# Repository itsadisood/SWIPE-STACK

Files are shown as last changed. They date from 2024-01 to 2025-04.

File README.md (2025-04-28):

# SWIPE-STACK

**SWIPE-STACK** is a modern re-implementation of the classic puzzle game *Tetris*, featuring a wireless glove controller and a dynamic LED-matrix-based main hub.

This project combines embedded systems design, wireless communication, real-time graphics processing, and custom hardware to create an innovative and portable gaming experience.

---

## Project Overview

The system consists of two main components:

### Glove Module
- **Input Device**: A wearable glove capturing hand movements and gestures.
- **Key Components**:
  - **IMU Sensor**: Collects motion and orientation data.
  - **STM32 Microcontroller**: Processes IMU data and converts it into game control inputs.
  - **HM19 Bluetooth Module**: Communicates inputs wirelessly to the hub via UART.
  - **LiPo Battery**: Powers the glove, with battery management provided by an off-the-shelf controller.

### Main Hub
- **Game Console**: Executes game logic, receives user input, and manages displays.
- **Key Components**:
  - **STM32 Microcontroller**: Runs the game engine and display drivers.
  - **HM19 Bluetooth Module**: Receives input data from the glove.
  - **64x32 LED Matrix Display**: Displays the active game screen, driven by a custom parallel interface using DMA and timers.
  - **OLED 16x2 Text Display**: Shows the current score and level via SPI.
  - **TI Buck Converter**: Provides regulated power for the system.

Each STM32 project (`Hub/` and `Glove/`) follows the typical CubeIDE structure, including source files (`Core/`), drivers (`Drivers/`), project configuration (`.ioc`), and build settings.

---

## Repository Structure

- **Hub/** – Firmware for the main hub (STM32 project using STM32Workbench)
- **Glove/** – Firmware for the glove controller (STM32 project using STM32Workbench)
- **Electrical/** – Hardware design files (schematics, PCB layouts)
- **Mechanical/** – Mechanical design files (CAD models for glove and hub enclosures)
- **README.md** – Project overview and documentation (this file)

---
## Features

- **Wireless Glove Controller**: Real-time gesture input using an IMU and STM32 MCU.
- **Bluetooth Communication**: Low-latency UART-based HM19 Bluetooth link.
- **Custom LED Matrix Driver**: High-speed, multiplexed driving of a 64x32 RGB LED matrix using DMA and timers.
- **Embedded Game Engine**: Fully on-board Tetris-like game running on STM32 microcontroller.
- **Text-Based Display**: OLED screen displaying real-time score and level information.
- **Portable and Modular Design**: Custom PCBs, enclosures, and battery-powered operation.

---

## Demo

Check out a live demo of SWIPE-STACK here:  
SWIPE-STACK Demo Video (https://www.youtube.com/watch?v=645_PaOeo9Y&t=164s)

👉 [Watch the demo on YouTube](https://www.youtube.com/watch?v=645_PaOeo9Y&t=164s)

---

## Contributors

- Aditya Sood
- Alex Chitsazzadeh
- Vishnu Lagudu
- Justin Cambridge

---

## Notes

- This project is not intended for direct plug-and-play usage.
- Hardware assembly, flashing, and Bluetooth setup are required to build a fully functioning system.
- Schematics and mechanical models are provided for reference and reproduction.
- All firmware was developed using [STM32SystemWorkbench](https://www.st.com/en/development-tools/stm32cubeide.html).

---

## Acknowledgments

- STM32Cube HAL Drivers
- Public domain versions of the classic Tetris game logic
- Open-source hardware design inspirations for LED matrix driving techniques

---

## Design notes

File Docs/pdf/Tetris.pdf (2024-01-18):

## TETRIS GAME LOGIC

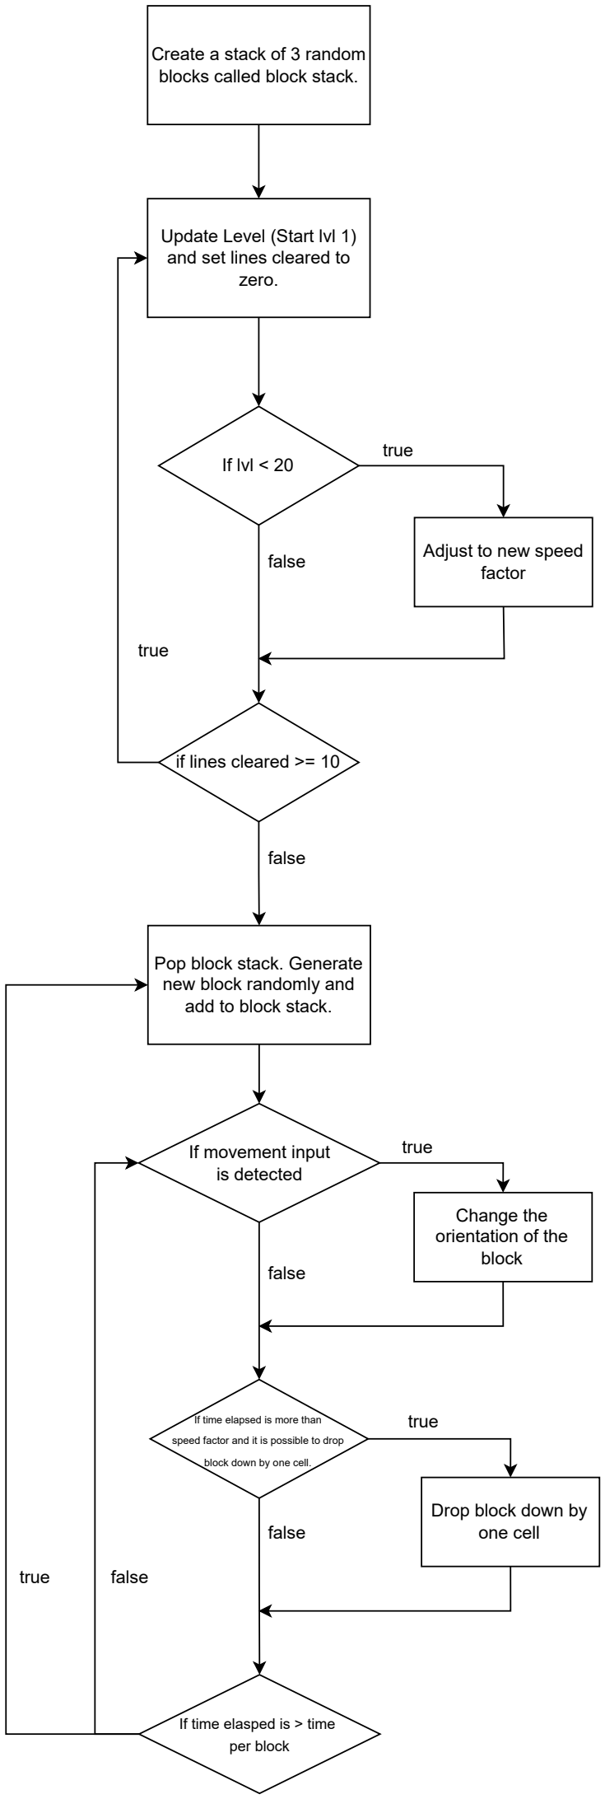
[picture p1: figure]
Update Level (Start lvl 1) and set lines cleared to zero.; Create a stack of 3 random blocks called block stack.; If lvl < 20; Adjust to new speed factor; true; false; if lines cleared >= 10; If movement input is detected; Change the orientation of the block; If time elapsed is more than; speed factor and it is possible to drop; block down by one cell.; Pop block stack. Generate new block randomly and add to block stack.; If time elasped is > time per block; Drop block down by one cell

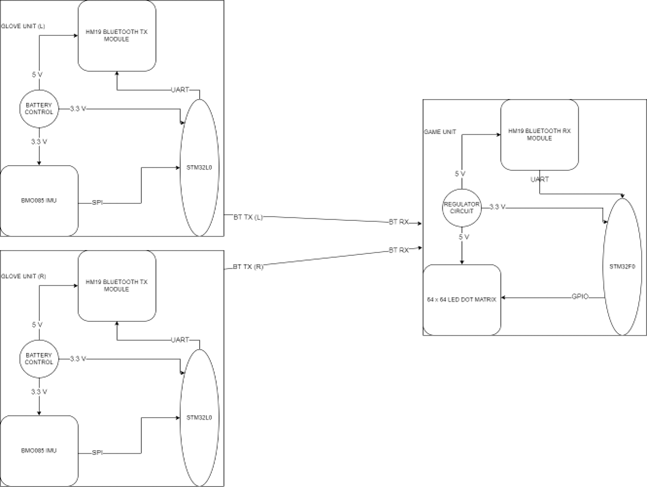
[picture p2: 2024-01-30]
Docs/pdf/Overall_System_Diagram.png

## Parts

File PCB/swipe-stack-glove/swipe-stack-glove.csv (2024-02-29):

# | Reference | Qty | Both Gloves | Value | Footprint | DNP
1 | C1, C2, C3, C6, C8, C9, C10, C11, C12, C13, C14 | 11 | 22 | 0.1uF | Capacitor_SMD:C_0805_2012Metric_Pad1.18x1.45mm_HandSolder
2 | C4, C5 | 2 | 4 | 22pF | Capacitor_SMD:C_0805_2012Metric_Pad1.18x1.45mm_HandSolder
3 | C7 | 1 | 2 | 10uF | Capacitor_SMD:C_0805_2012Metric_Pad1.18x1.45mm_HandSolder
4 | D1, D2 | 2 | 4 | green | LED_SMD:LED_0805_2012Metric_Pad1.15x1.40mm_HandSolder
5 | D3 | 1 | 2 | red | LED_SMD:LED_0805_2012Metric_Pad1.15x1.40mm_HandSolder
6 | D4 | 1 | 2 | blue | LED_SMD:LED_0805_2012Metric_Pad1.15x1.40mm_HandSolder
7 | H1 | 1 | 2 | B_TopLeft | MountingHole:MountingHole_2.5mm
8 | H2 | 1 | 2 | B_TopRight | MountingHole:MountingHole_2.5mm
9 | H3 | 1 | 2 | B_BottomLeft | MountingHole:MountingHole_2.5mm
10 | H4 | 1 | 2 | B_BottomRight | MountingHole:MountingHole_2.5mm
11 | J2 | 1 | 2 | Polulu Regulator | Connector_PinHeader_2.54mm:PinHeader_1x05_P2.54mm_Vertical
12 | J3, J4, J5 | 3 | 6 | Conn_01x01_Pin | Connector_PinHeader_2.54mm:PinHeader_1x01_P2.54mm_Vertical
13 | J6 | 1 | 2 | Conn_01x04 | Connector_PinHeader_2.54mm:PinHeader_1x04_P2.54mm_Vertical
14 | R1, R6 | 2 | 4 | 100k | Resistor_SMD:R_0805_2012Metric_Pad1.20x1.40mm_HandSolder
15 | R2, R3, R7 | 3 | 6 | 1k | Resistor_SMD:R_0805_2012Metric_Pad1.20x1.40mm_HandSolder
16 | R4 | 1 | 2 | 470 | Resistor_SMD:R_0805_2012Metric_Pad1.20x1.40mm_HandSolder
17 | R9, R11, R12 | 3 | 6 | 1k | LED_SMD:LED_0805_2012Metric_Pad1.15x1.40mm_HandSolder
18 | R10 | 1 | 2 | 510 | LED_SMD:LED_0805_2012Metric_Pad1.15x1.40mm_HandSolder
19 | SW1, SW2, SW3, SW4 | 4 | 8 | SW_Push | Button_Switch_SMD:SW_SPST_Omron_B3FS-100xP | digikey
20 | U1 | 1 | 2 | STM32F091RCTx | Package_QFP:LQFP-64_10x10mm_P0.5mm | digikey
21 | U2 | 1 | 2 | BNO085 | Package_LGA:LGA-28_5.2x3.8mm_P0.5mm
22 | U3 | 1 | 2 | MAX7375AXR805 | Package_TO_SOT_SMD:SOT-323_SC-70_Handsoldering
23 | U4 | 1 | 2 | HM-19 | GlovePCB:HM-11-MODULE
24 | U5 | 1 | 2 | Adafruit Charger | GlovePCB:AdaFruit Charger | ada
25 | U6 | 1 | 2 | BatteryCell | GlovePCB:battery_cell | ada
26 | XTAL1 | 1 | 2 | ECX-.327-CDX-1293 | GlovePCB:XTAL_ECS-.327-12.5-34RR-TR

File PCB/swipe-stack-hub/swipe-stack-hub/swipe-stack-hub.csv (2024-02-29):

Source: | C:\Users\justi\Documents\SWIPE-STACK\PCB\swipe-stack-hub\swipe-stack-hub.kicad_sch
Date: | 2/21/2024 10:18:29 AM
Tool: | Eeschema 7.0.10
Generator: | C:\Users\justi\AppData\Local\Programs\KiCad\7.0\bin\scripting\plugins/bom_csv_grouped_by_value.py
Component Count: | 60
Collated Components:
Item | Qty | Reference(s) | Value | LibPart | Footprint | Datasheet | DNP | Description
1 | 2 | C1, C3 | 10uF | Device:C_Small | Capacitor_SMD:C_0805_2012Metric_Pad1.18x1.45mm_HandSolder | ~
2 | 4 | C2, C4, C6, Cboot1 | 0.1uF | Device:C_Small | Capacitor_SMD:C_0805_2012Metric_Pad1.18x1.45mm_HandSolder | ~
3 | 5 | C5, C7, C8, C9, C10 | .1uF | Device:C | Capacitor_SMD:C_0805_2012Metric_Pad1.18x1.45mm_HandSolder | ~
4 | 1 | C11 | 250uF | Device:C_Polarized_Small | Capacitor_SMD:C_0805_2012Metric_Pad1.18x1.45mm_HandSolder | ~
5 | 1 | C12 | .05uF | Device:C | Capacitor_SMD:C_0805_2012Metric_Pad1.18x1.45mm_HandSolder | ~
6 | 2 | Cin1, Cin2 | 2.2uF | Device:C_Small | Capacitor_SMD:C_0805_2012Metric_Pad1.18x1.45mm_HandSolder | ~
7 | 1 | Cout1 | 22uF | Device:C_Small | Capacitor_SMD:C_0805_2012Metric_Pad1.18x1.45mm_HandSolder | ~
8 | 2 | D1, D2 | LED1 | Device:LED | LED_SMD:LED_0805_2012Metric_Pad1.15x1.40mm_HandSolder | ~
9 | 1 | FB1 | Ferrite Bead | stm32f091-rescue:Ferrite_Bead_Small-Device | Inductor_SMD:L_0805_2012Metric_Pad1.15x1.40mm_HandSolder
10 | 1 | J1 | Barrel_Jack_Switch | Connector:Barrel_Jack_Switch | Connector_BarrelJack:BarrelJack_CUI_PJ-036AH-SMT_Horizontal | ~
11 | 1 | J2 | Conn_02x08_Odd_Even | Connector_Generic:Conn_02x08_Odd_Even | Connector_IDC:IDC-Header_2x08_P2.54mm_Vertical_SMD | ~
12 | 1 | J3 | Conn_02x05_Odd_Even | Connector_Generic:Conn_02x05_Odd_Even | Connector_IDC:IDC-Header_2x05_P2.54mm_Vertical_SMD | ~
13 | 1 | J4 | Conn_01x06 | Connector_Generic:Conn_01x06 | Connector_JST:JST_EH_B6B-EH-A_1x06_P2.50mm_Vertical | ~
14 | 1 | J5 | Conn_01x04 | Connector_Generic:Conn_01x04 | Connector_JST:JST_EH_B4B-EH-A_1x04_P2.50mm_Vertical | ~
15 | 4 | J6, J7, J8, J9 | Conn_01x01_Socket | Connector:Conn_01x01_Socket | Connector_PinSocket_2.54mm:PinSocket_1x01_P2.54mm_Vertical | ~
16 | 1 | L1 | 10uH | Device:L_Small | Inductor_SMD:L_0805_2012Metric_Pad1.15x1.40mm_HandSolder | ~
17 | 1 | LD1 | LED_Yellow | stm32f091-rescue:LED_Small_ALT-Device | LED_SMD:LED_0805_2012Metric_Pad1.15x1.40mm_HandSolder
18 | 1 | LD2 | LED_Green | stm32f091-rescue:LED_Small_ALT-Device | LED_SMD:LED_0805_2012Metric_Pad1.15x1.40mm_HandSolder
19 | 1 | LD3 | LED_Red | stm32f091-rescue:LED_Small_ALT-Device | LED_SMD:LED_0805_2012Metric_Pad1.15x1.40mm_HandSolder
20 | 1 | LS1 | Speaker | Device:Speaker | 477:Speaker | ~
21 | 4 | R1, R2, R4, R5 | 1k | Device:R_Small_US | Resistor_SMD:R_0805_2012Metric_Pad1.20x1.40mm_HandSolder | ~
22 | 3 | R3, R6, R14 | 470 | Device:R_Small_US | Resistor_SMD:R_0805_2012Metric_Pad1.20x1.40mm_HandSolder | ~
23 | 4 | R7, R10, R12, R13 | 1k | Device:R_US | Resistor_SMD:R_0805_2012Metric_Pad1.20x1.40mm_HandSolder | ~
24 | 1 | R8 | 100K | Device:R_US | Resistor_SMD:R_0805_2012Metric_Pad1.20x1.40mm_HandSolder | ~
25 | 1 | R9 | 100k | Device:R_Small_US | Resistor_SMD:R_0805_2012Metric_Pad1.20x1.40mm_HandSolder | ~
26 | 1 | R11 | 2k | Device:R_US | Resistor_SMD:R_0805_2012Metric_Pad1.20x1.40mm_HandSolder | ~
27 | 1 | Rfbb1 | 22.1k | Device:R_Small_US | Resistor_SMD:R_0805_2012Metric_Pad1.20x1.40mm_HandSolder | ~
28 | 1 | Rfbt1 | 69.8k | Device:R_Small_US | Resistor_SMD:R_0805_2012Metric_Pad1.20x1.40mm_HandSolder | ~
29 | 3 | SW1, SW2, SW3 | ~ | Switch:SW_Push | Button_Switch_SMD:SW_SPST_PTS645 | ~
30 | 2 | SW4, SW5 | SW_Push | Switch:SW_Push | Button_Switch_SMD:SW_SPST_PTS645 | ~
31 | 1 | U1 | STM32F091RCTx | MCU_ST_STM32F0:STM32F091RCTx | Package_QFP:LQFP-64_10x10mm_P0.5mm | https://www.st.com/resource/en/datasheet/stm32f091rc.pdf
32 | 1 | U2 | LMR51430 (LMR54410) | Regulator_Switching:LMR51430 | Package_TO_SOT_SMD:SOT-23-6 | https://www.ti.com/lit/ds/symlink/lmr51430.pdf
33 | 1 | U3 | HM19R | HM11-19:CC2640R2FRGZR | 477:HM-11-MODULE |  |  | SimpleLink™ 32-bit Arm® Cortex®-M3 Bluetooth® 5.1 Low Energy wireless MCU with 128-kB flash
34 | 1 | U4 | HM19L | HM11-19:CC2640R2FRGZR | 477:HM-11-MODULE |  |  | SimpleLink™ 32-bit Arm® Cortex®-M3 Bluetooth® 5.1 Low Energy wireless MCU with 128-kB flash
35 | 1 | U5 | MAX7375AXR805 | Oscillator:MAX7375AXR805 | Package_TO_SOT_SMD:SOT-323_SC-70_Handsoldering | https://datasheets.maximintegrated.com/en/ds/MAX7375.pdf
36 | 1 | U6 | LM386 | Amplifier_Audio:LM386 | Package_SO:SOIC-8-1EP_3.9x4.9mm_P1.27mm_EP2.29x3mm | http://www.ti.com/lit/ds/symlink/lm386.pdf

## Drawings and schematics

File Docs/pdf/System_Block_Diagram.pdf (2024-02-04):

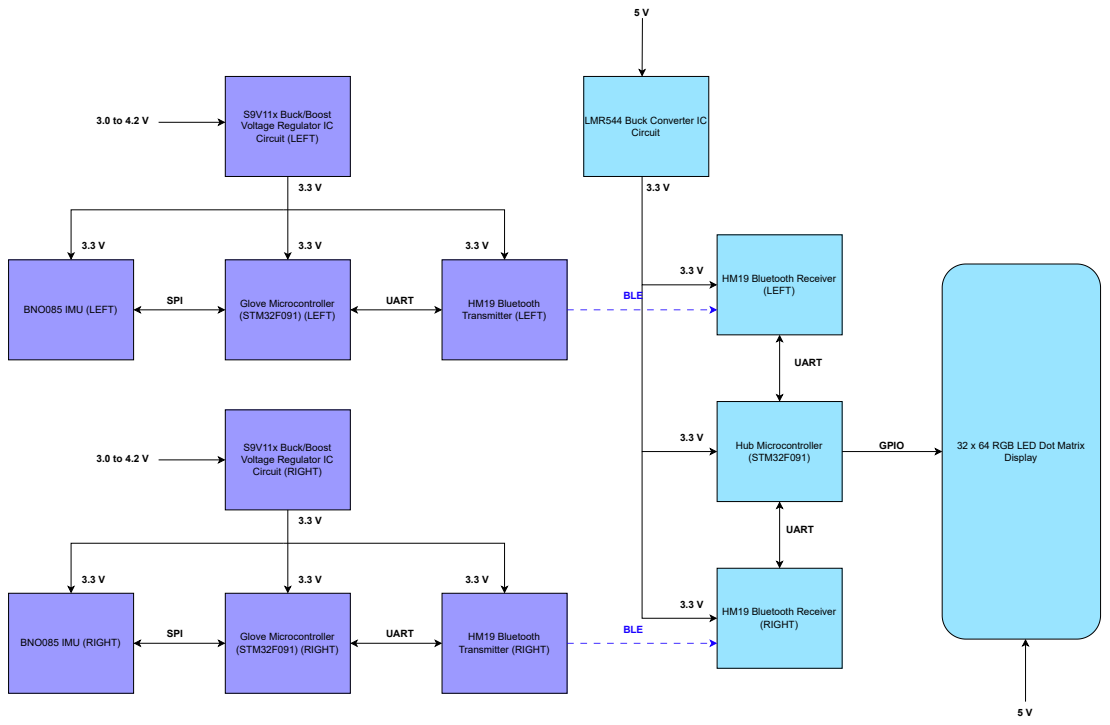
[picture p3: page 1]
Hub Microcontroller (STM32F091); Display; GPIO; HM19 Bluetooth Receiver (LEFT); HM19 Bluetooth Receiver (RIGHT); UART; Circuit; Glove Microcontroller (STM32F091) (LEFT); HM19 Bluetooth Transmitter (LEFT); BNO085 IMU (LEFT); SPI; BLE; Glove Microcontroller (STM32F091) (RIGHT); HM19 Bluetooth Transmitter (RIGHT); BNO085 IMU (RIGHT)

S9V11x Buck/Boost
Voltage Regulator IC
Circuit (LEFT)

LMR544 Buck Converter IC

Circuit (RIGHT)

32 x 64 RGB LED Dot Matrix

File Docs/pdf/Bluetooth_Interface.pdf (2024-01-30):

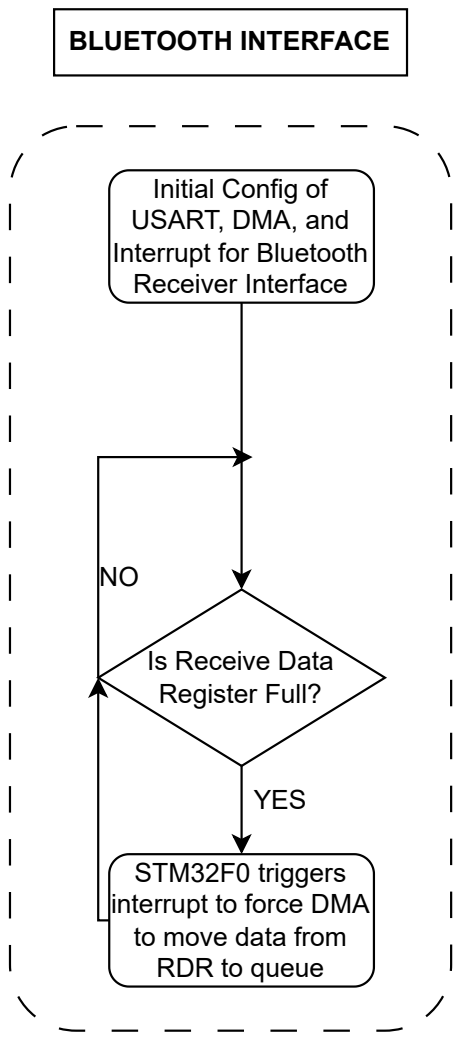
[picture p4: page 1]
YES; BLUETOOTH INTERFACE

Initial Config of
USART, DMA, and
Interrupt for Bluetooth
Receiver Interface

Is Receive Data
Register Full?

STM32F0 triggers
interrupt to force DMA
to move data from
RDR to queue

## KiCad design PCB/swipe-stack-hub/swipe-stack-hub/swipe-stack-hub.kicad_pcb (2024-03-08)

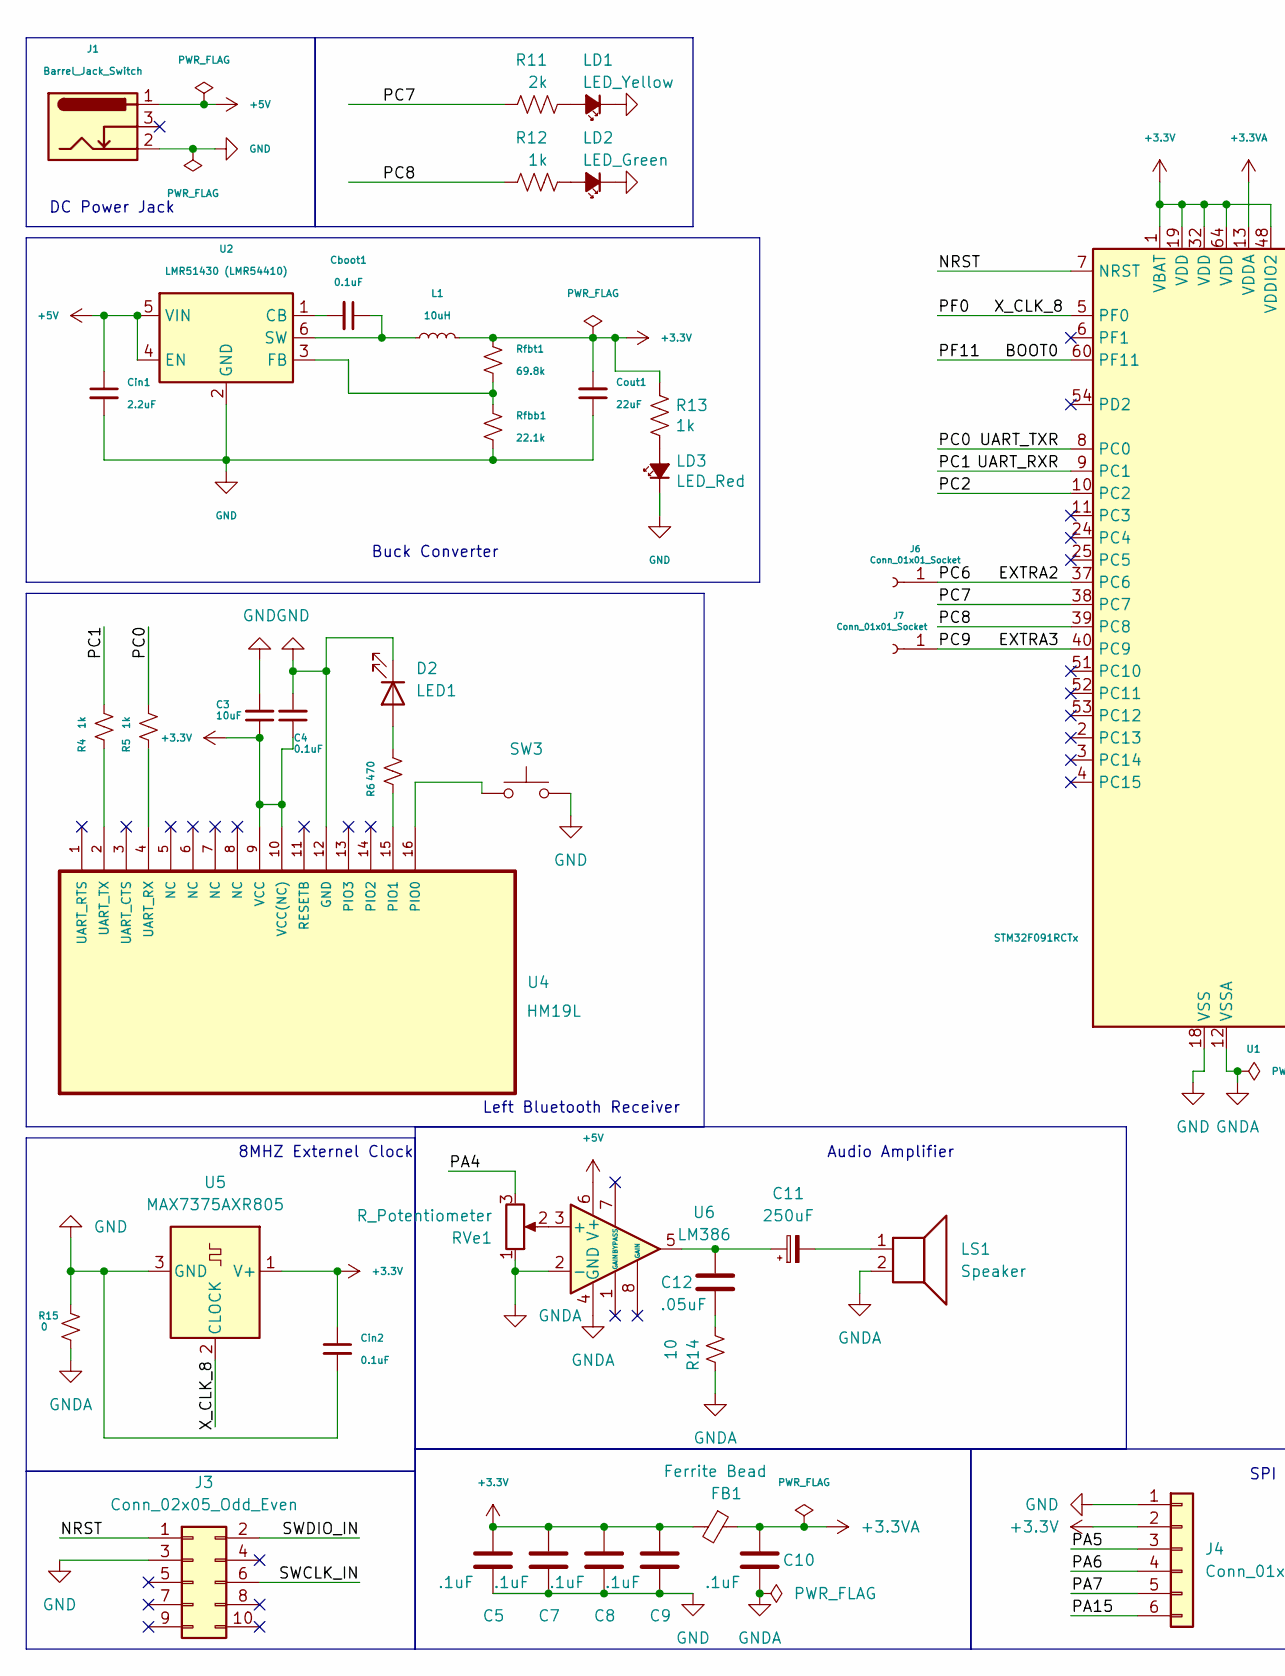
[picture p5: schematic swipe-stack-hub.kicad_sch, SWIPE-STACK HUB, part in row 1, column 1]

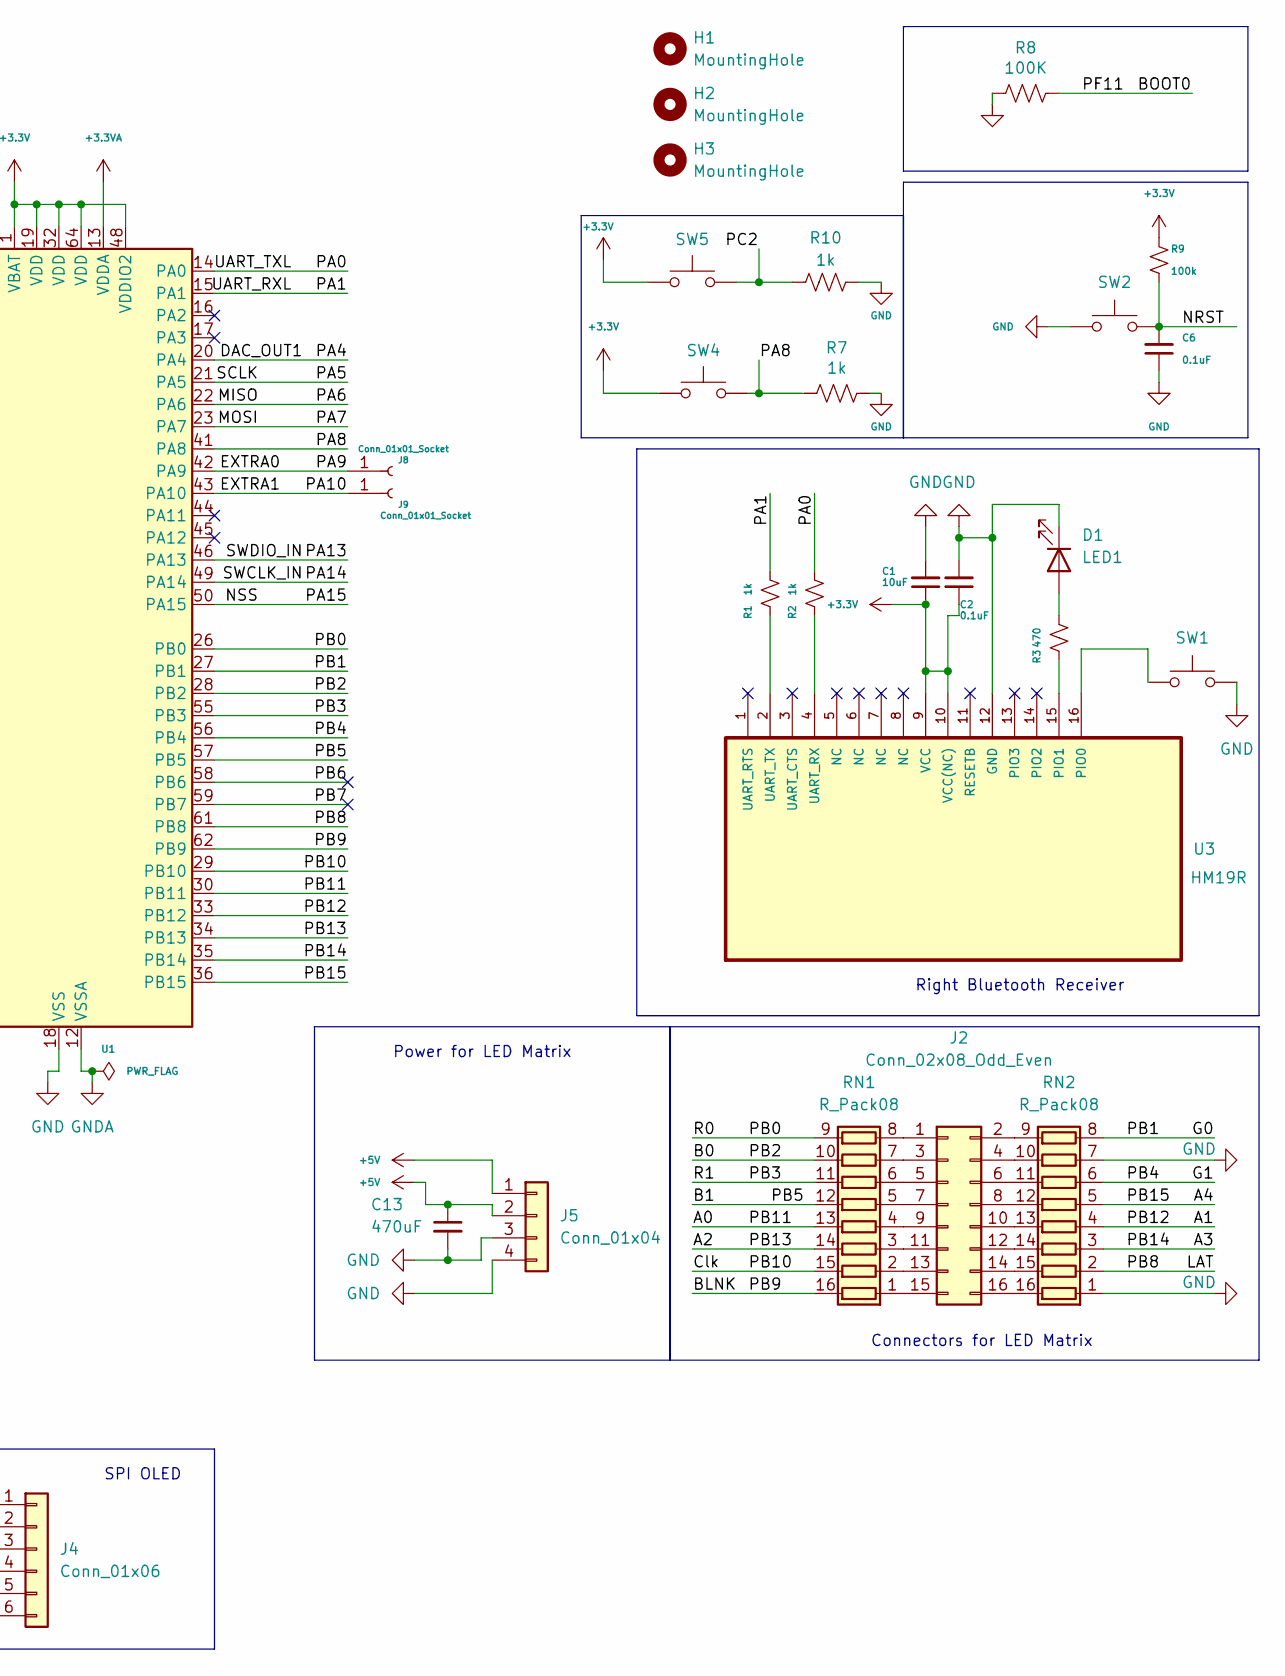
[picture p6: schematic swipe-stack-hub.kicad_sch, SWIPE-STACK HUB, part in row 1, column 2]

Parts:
C1, C3: 10uF; C_0805_2012Metric_Pad1.18x1.45mm_HandSolder
C2, C4, C6: 0.1uF; C_0805_2012Metric_Pad1.18x1.45mm_HandSolder
C5, C7, C8, C9, C10: .1uF; C_0805_2012Metric_Pad1.18x1.45mm_HandSolder
C11: 250uF; CP_Radial_D14.0mm_P5.00mm
C12: .05uF; C_0805_2012Metric_Pad1.18x1.45mm_HandSolder
C13: 470uF; CP_Radial_D14.0mm_P5.00mm
Cboot1: 0.1uF; C_0805_2012Metric_Pad1.18x1.45mm_HandSolder
Cin1: 2.2uF; C_0805_2012Metric_Pad1.18x1.45mm_HandSolder
Cin2: 0.1uF; C_0805_2012Metric_Pad1.18x1.45mm_HandSolder
Cout1: 22uF; CP_Radial_D5.0mm_P2.50mm
D1, D2: LED1; LED_0805_2012Metric_Pad1.15x1.40mm_HandSolder
FB1: Ferrite Bead; L_0805_2012Metric_Pad1.15x1.40mm_HandSolder
H1, H2, H3: MountingHole; MountingHole_3mm
J1: Barrel_Jack_Switch; BarrelJack_CUI_PJ-036AH-SMT_Horizontal
J2: Conn_02x08_Odd_Even; IDC-Header_2x08_P2.54mm_Vertical_SMD
J3: Conn_02x05_Odd_Even; IDC-Header_2x05_P2.54mm_Vertical
J4: Conn_01x06; JST_VH_B6P-VH-B_1x06_P3.96mm_Vertical
J5: Conn_01x04; JST_VH_B4P-VH-B_1x04_P3.96mm_Vertical
J6, J7, J8, J9: Conn_01x01_Socket; PinSocket_1x01_P2.54mm_Vertical
L1: 10uH; L_0805_2012Metric_Pad1.15x1.40mm_HandSolder
LD1: LED_Yellow; LED_0805_2012Metric_Pad1.15x1.40mm_HandSolder
LD2: LED_Green; LED_0805_2012Metric_Pad1.15x1.40mm_HandSolder
LD3: LED_Red; LED_0805_2012Metric_Pad1.15x1.40mm_HandSolder
LS1: Speaker; JST_VH_B2P-VH-FB-B_1x02_P3.96mm_Vertical
R1, R2, R4, R5, R7, R10, R12, R13: 1k; R_0805_2012Metric_Pad1.20x1.40mm_HandSolder
R3, R6: 470; R_0805_2012Metric_Pad1.20x1.40mm_HandSolder
R8: 100K; R_0805_2012Metric_Pad1.20x1.40mm_HandSolder
R9: 100k; R_0805_2012Metric_Pad1.20x1.40mm_HandSolder
R11: 2k; R_0805_2012Metric_Pad1.20x1.40mm_HandSolder
R14: 10; R_0805_2012Metric_Pad1.20x1.40mm_HandSolder
R15: 0; R_0805_2012Metric_Pad1.20x1.40mm_HandSolder
RN1, RN2: R_Pack08; SOIC127P762X240-16N
RVe1: R_Potentiometer; Potentiometer_Bourns_PTV09A-1_Single_Vertical
Rfbb1: 22.1k; R_0805_2012Metric_Pad1.20x1.40mm_HandSolder
Rfbt1: 69.8k; R_0805_2012Metric_Pad1.20x1.40mm_HandSolder
SW1, SW2, SW3: SW_SPST_PTS645
SW4, SW5: SW_Push; SW_SPST_PTS645
U1: STM32F091RCTx; LQFP-64_10x10mm_P0.5mm
U2: LMR51430 (LMR54410); SOT-23-6
U3: HM19R; HM-19-MODULE
U4: HM19L; HM-19-MODULE
U5: MAX7375AXR805; SOT-323_SC-70_Handsoldering
U6: LM386; SOIC-8-1EP_3.9x4.9mm_P1.27mm_EP2.29x3mm

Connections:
+3.3V: C1.1, C2.1, C3.1, C4.1, C5.1, C7.1, C8.1, C9.1, Cin2.1, Cout1.2, FB1.2, J4.2, L1.2, R9.1, R13.1, Rfbt1.1, SW4.1, SW5.1, U1.1 (VBAT), U1.19 (VDD), U1.32 (VDD), U1.48 (VDDIO2), U1.64 (VDD), U3.9 (VCC), U3.10 (VCC(NC)), U4.9 (VCC), U4.10 (VCC(NC)), U5.1 (V+)
+3.3VA: C10.1, FB1.1, U1.13 (VDDA)
+5V: C13.1, Cin1.1, J1.1, J5.1, J5.2, U2.4 (EN), U2.5 (VIN), U6.6 (V+)
/A0: RN1.13 (R4.2), U1.30 (PB11)
/A1: RN2.4 (R4.1), U1.33 (PB12)
/A2: RN1.14 (R3.2), U1.34 (PB13)
/A3: RN2.3 (R3.1), U1.35 (PB14)
/A4: RN2.5 (R5.1), U1.36 (PB15)
/B0: RN1.10 (R7.2), U1.28 (PB2)
/B1: RN1.12 (R5.2), U1.57 (PB5)
/BLNK: RN1.16 (R1.2), U1.62 (PB9)
/BOOT0: R8.1, U1.60 (PF11)
/Clk: RN1.15 (R2.2), U1.29 (PB10)
/DAC_OUT1: RVe1.3, U1.20 (PA4)
/EXTRA0: J8.1, U1.42 (PA9)
/EXTRA1: J9.1, U1.43 (PA10)
/EXTRA2: J6.1, U1.37 (PC6)
/EXTRA3: J7.1, U1.40 (PC9)
/G0: RN2.8 (R8.1), U1.27 (PB1)
/G1: RN2.6 (R6.1), U1.56 (PB4)
/LAT: RN2.2 (R2.1), U1.61 (PB8)
/MISO: J4.4, U1.22 (PA6)
/MOSI: J4.5, U1.23 (PA7)
/NRST: C6.2, J3.1, R9.2, SW2.2, U1.7 (NRST)
/NSS: J4.6, U1.50 (PA15)
/PA0: R2.2, U1.14 (PA0)
/PA1: R1.2, U1.15 (PA1)
/PA5: J4.3, U1.21 (PA5)
/PA8: R7.2, SW4.2, U1.41 (PA8)
/PA13: J3.2, U1.46 (PA13)
/PA14: J3.6, U1.49 (PA14)
/PB0: RN1.9 (R8.2), U1.26 (PB0)
/PB3: RN1.11 (R6.2), U1.55 (PB3)
/PB6: U1.58 (PB6)
/PB7: U1.59 (PB7)
/PC0: R5.2, U1.8 (PC0)
/PC1: R4.2, U1.9 (PC1)
/PC2: R10.1, SW5.2, U1.10 (PC2)
/PC7: R11.2, U1.38 (PC7)
/PC8: R12.2, U1.39 (PC8)
/PF0: U1.5 (PF0), U5.2 (CLOCK)
GND: C1.2, C2.2, C3.2, C4.2, C5.2, C6.1, C7.2, C8.2, C9.2, C13.2, Cin1.2, Cin2.2, Cout1.1, D1.1 (K), D2.1 (K), J1.2, J3.3, J4.1, J5.3, J5.4, LD1.1 (K), LD2.1 (K), LD3.1 (K), R7.1, R8.2, R10.2, R15.2, RN2.1 (R1.1), RN2.7 (R7.1), Rfbb1.2, SW1.2, SW2.1, SW3.2, U1.18 (VSS), U1.31 (VSS), U1.47 (VSS), U1.63 (VSS), U2.2 (GND), U3.12 (GND), U4.12 (GND), U5.3 (GND)
GNDA: C10.2, LS1.2, R14.1, R15.1, RVe1.1, U1.12 (VSSA), U6.2 (-), U6.4 (GND)
unnamed: C11.1, C12.1, U6.5
unnamed: C11.2, LS1.1
unnamed: C12.2, R14.2
unnamed: D1.2 (A), R3.2
unnamed: D2.2 (A), R6.2
unnamed: J2.1, RN1.8 (R8.1)
unnamed: J2.2, RN2.9 (R8.2)
unnamed: J2.3, RN1.7 (R7.1)
unnamed: J2.4, RN2.10 (R7.2)
unnamed: J2.5, RN1.6 (R6.1)
unnamed: J2.6, RN2.11 (R6.2)
unnamed: J2.7, RN1.5 (R5.1)
unnamed: J2.8, RN2.12 (R5.2)
unnamed: J2.9, RN1.4 (R4.1)
unnamed: J2.10, RN2.13 (R4.2)
unnamed: J2.11, RN1.3 (R3.1)
unnamed: J2.12, RN2.14 (R3.2)
unnamed: J2.13, RN1.2 (R2.1)
unnamed: J2.14, RN2.15 (R2.2)
unnamed: J2.15, RN1.1 (R1.1)
unnamed: J2.16, RN2.16 (R1.2)
unnamed: LD1.2 (A), R11.1
unnamed: LD2.2 (A), R12.1
unnamed: LD3.2 (A), R13.2
unnamed: Cboot1.2, U2.1 (CB)
unnamed: Rfbb1.1, Rfbt1.2, U2.3 (FB)
unnamed: Cboot1.1, L1.1, U2.6 (SW)
unnamed: SW1.1, U3.16 (PIO0)
unnamed: R3.1, U3.15 (PIO1)
unnamed: R2.1, U3.4 (UART_RX)
unnamed: R1.1, U3.2 (UART_TX)
unnamed: SW3.1, U4.16 (PIO0)
unnamed: R6.1, U4.15 (PIO1)
unnamed: R5.1, U4.4 (UART_RX)
unnamed: R4.1, U4.2 (UART_TX)
unnamed: RVe1.2, U6.3 (+)

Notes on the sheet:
Right Bluetooth Receiver
Audio Amplifier
Buck Converter
SPI OLED
Power for LED Matrix
Connectors for LED Matrix
8MHZ Externel Clock
Left Bluetooth Receiver
DC Power Jack

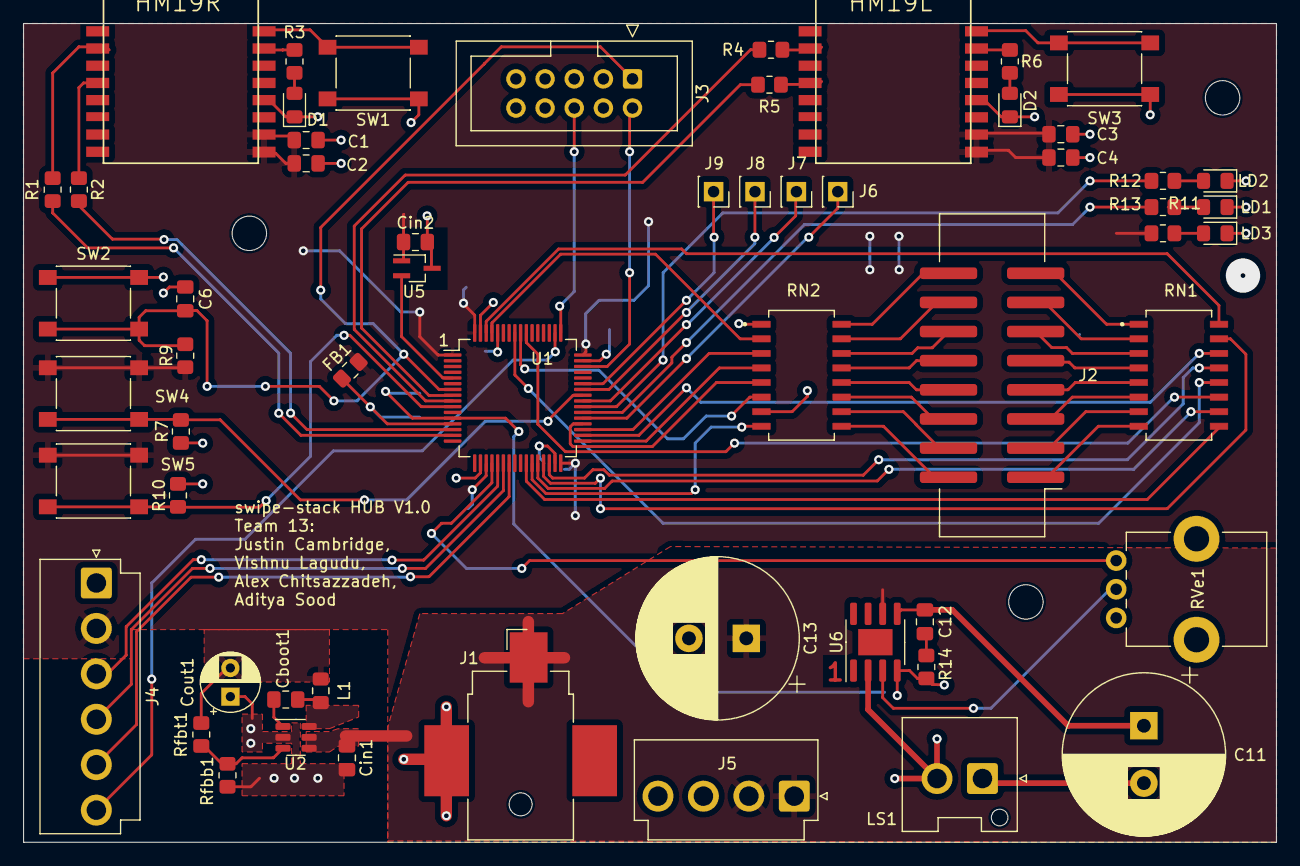
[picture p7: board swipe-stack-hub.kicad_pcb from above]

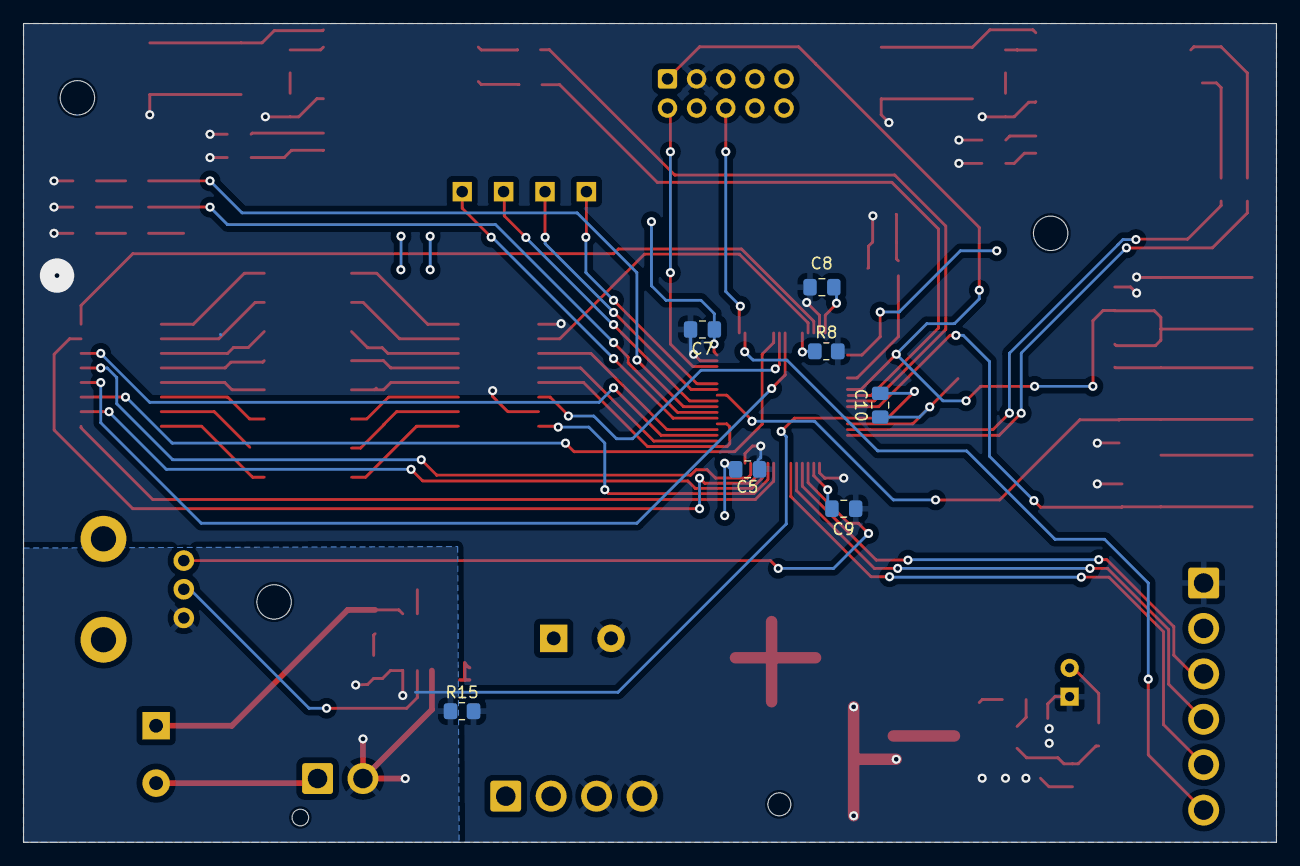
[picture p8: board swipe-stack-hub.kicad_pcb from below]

Board: 2 copper layers, 109.2 x 71.4 mm, 68 parts (7 on the bottom side), 77 nets.

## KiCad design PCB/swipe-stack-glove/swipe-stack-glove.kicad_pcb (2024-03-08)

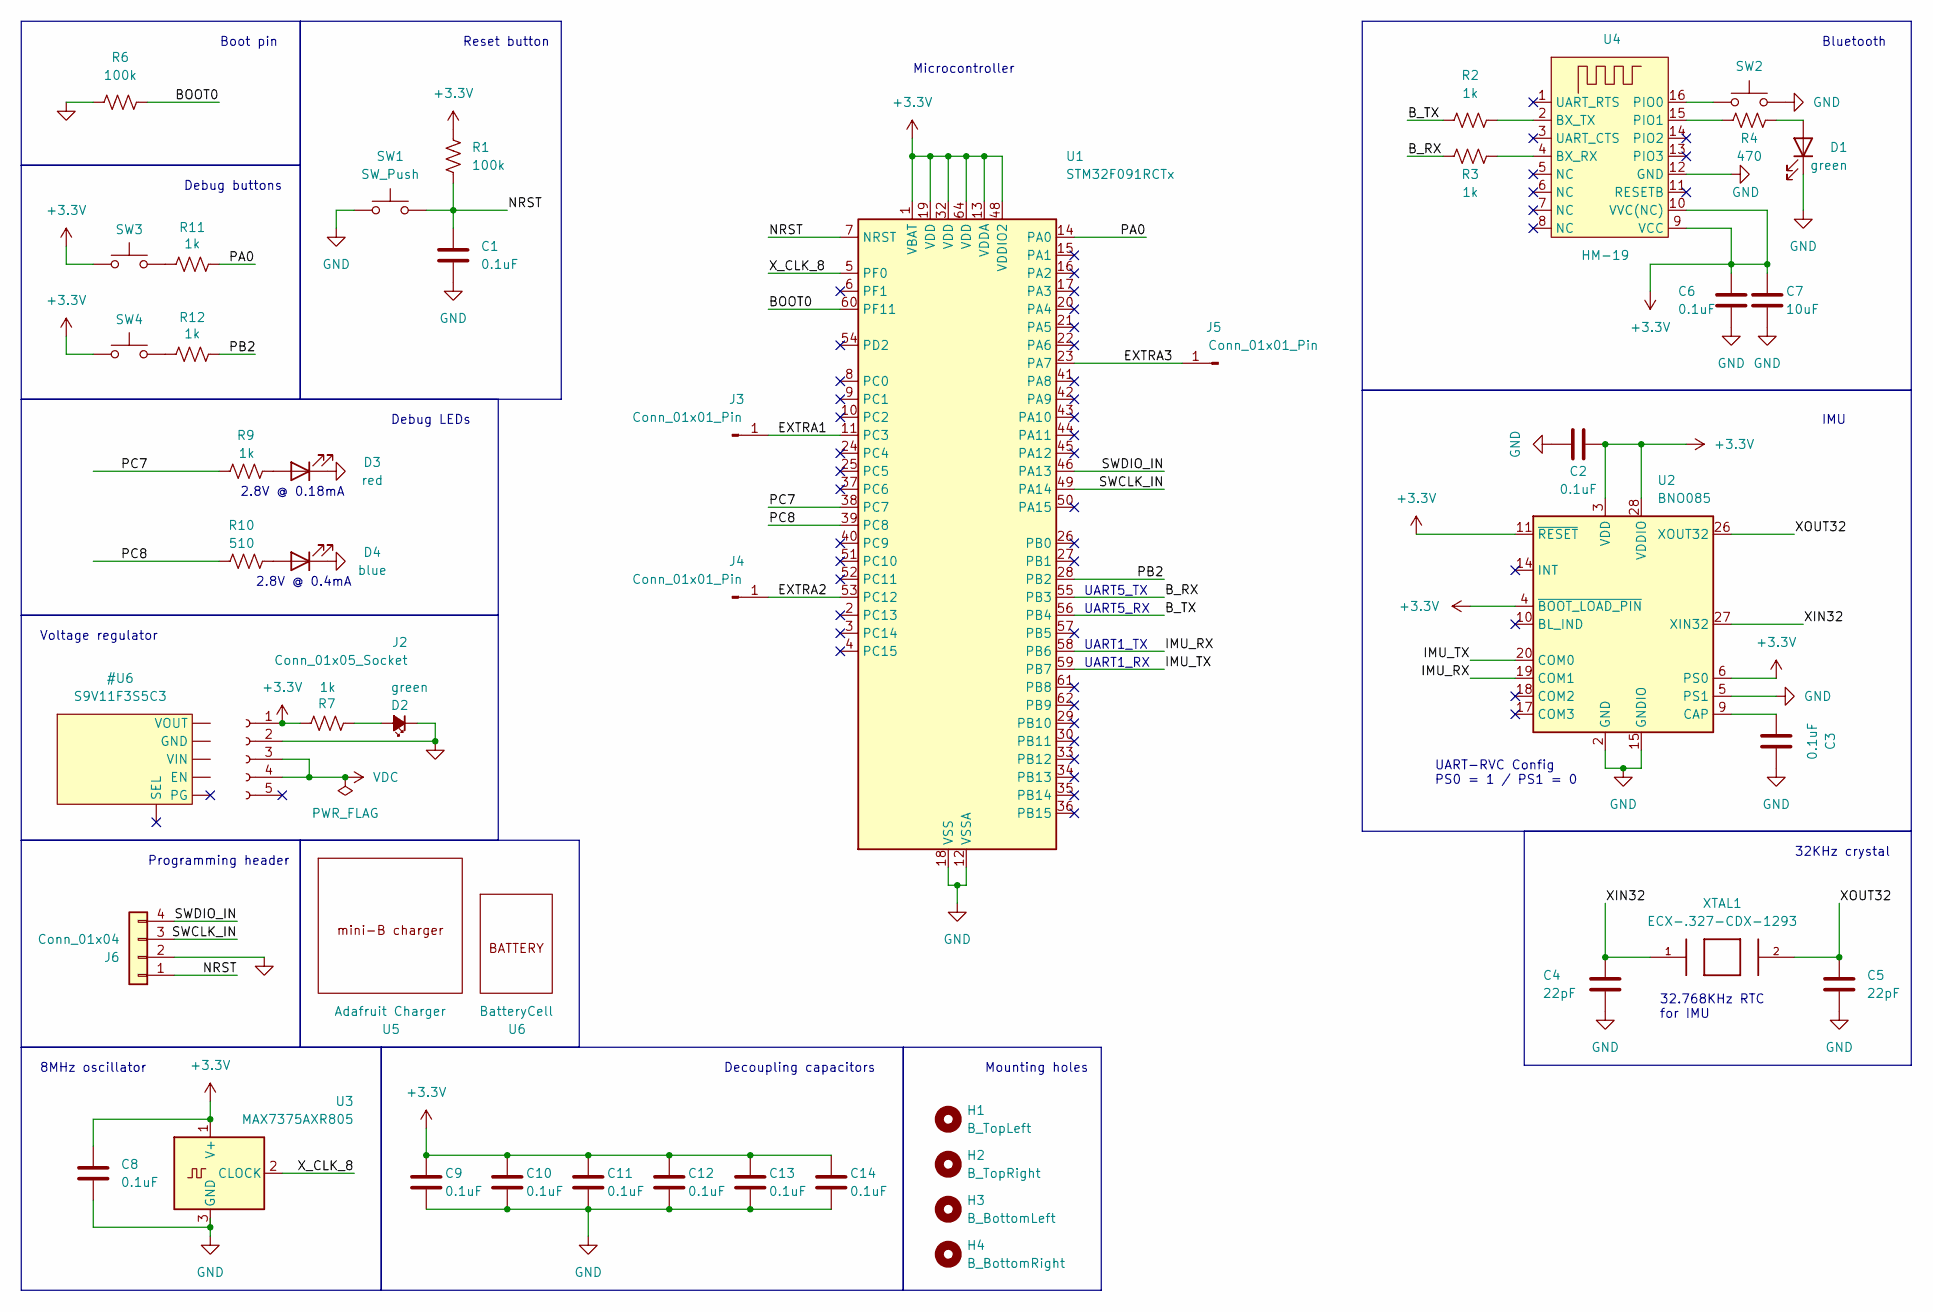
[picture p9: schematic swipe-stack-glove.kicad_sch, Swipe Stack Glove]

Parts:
C1, C2, C3, C6, C8, C9, C10, C11, C12, C13, C14: 0.1uF; C_0805_2012Metric_Pad1.18x1.45mm_HandSolder
C4, C5: 22pF; C_0805_2012Metric_Pad1.18x1.45mm_HandSolder
C7: 10uF; C_0805_2012Metric_Pad1.18x1.45mm_HandSolder
D1, D2: green; LED_0805_2012Metric_Pad1.15x1.40mm_HandSolder
D3: red; LED_0805_2012Metric_Pad1.15x1.40mm_HandSolder
D4: blue; LED_0805_2012Metric_Pad1.15x1.40mm_HandSolder
H1: B_TopLeft; MountingHole_2.5mm
H2: B_TopRight; MountingHole_2.5mm
H3: B_BottomLeft; MountingHole_2.5mm
H4: B_BottomRight; MountingHole_2.5mm
J2: Conn_01x05_Socket; PinHeader_1x05_P2.54mm_Vertical
J3, J4, J5: Conn_01x01_Pin; PinHeader_1x01_P2.54mm_Vertical
J6: Conn_01x04; PinHeader_1x04_P2.54mm_Vertical
R1, R6: 100k; R_0805_2012Metric_Pad1.20x1.40mm_HandSolder
R2, R3, R7: 1k; R_0805_2012Metric_Pad1.20x1.40mm_HandSolder
R4: 470; R_0805_2012Metric_Pad1.20x1.40mm_HandSolder
R9, R11, R12: 1k; LED_0805_2012Metric_Pad1.15x1.40mm_HandSolder
R10: 510; LED_0805_2012Metric_Pad1.15x1.40mm_HandSolder
SW1, SW2, SW3, SW4: SW_Push; SW_SPST_Omron_B3FS-100xP
U1: STM32F091RCTx; LQFP-64_10x10mm_P0.5mm
U2: BNO085; LGA-28_5.2x3.8mm_P0.5mm
U3: MAX7375AXR805; SOT-323_SC-70_Handsoldering
U4: HM-19; HM-11-MODULE
U5: Adafruit Charger; AdaFruit Charger
U6: BatteryCell; battery_cell
XTAL1: ECX-.327-CDX-1293; XTAL_ECS-.327-12.5-34RR-TR

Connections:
+3.3V: C2.2, C6.1, C7.1, C8.1, C9.1, C10.1, C11.1, C12.1, C13.1, C14.1, J2.1, R1.1, R7.1, SW3.1, SW4.1, U1.1 (VBAT), U1.13 (VDDA), U1.19 (VDD), U1.32 (VDD), U1.48 (VDDIO2), U1.64 (VDD), U2.3 (VDD), U2.4 (~BOOT_LOAD_PIN), U2.6 (PS0), U2.11 (~RESET), U2.28 (VDDIO), U3.1 (V+), U4.9 (VCC), U4.10 (VVC(NC))
/BOOT0: R6.2, U1.60 (PF11)
/B_RX: R3.1, U1.55 (PB3)
/B_TX: R2.1, U1.56 (PB4)
/EXTRA1: J3.1, U1.11 (PC3)
/EXTRA2: J4.1, U1.53 (PC12)
/EXTRA3: J5.1, U1.23 (PA7)
/IMU_RX: U1.58 (PB6), U2.19 (COM1)
/IMU_TX: U1.59 (PB7), U2.20 (COM0)
/NRST: C1.1, J6.1, R1.2, SW1.2, U1.7 (NRST)
/PA0: R11.1, U1.14 (PA0)
/PB2: R12.1, U1.28 (PB2)
/PC7: R9.2, U1.38 (PC7)
/PC8: R10.2, U1.39 (PC8)
/SWCLK_IN: J6.3, U1.49 (PA14)
/SWDIO_IN: J6.4, U1.46 (PA13)
/XIN32: C4.1, U2.27 (XIN32), XTAL1.1
/XOUT32: C5.1, U2.26 (XOUT32), XTAL1.2
/X_CLK_8: U1.5 (PF0), U3.2 (CLOCK)
GND: C1.2, C2.1, C3.2, C4.2, C5.2, C6.2, C7.2, C8.2, C9.2, C10.2, C11.2, C12.2, C13.2, C14.2, D1.1 (K), D2.1 (K), D3.1 (K), D4.1 (K), J2.2, J6.2, R6.1, SW1.1, SW2.2, U1.12 (VSSA), U1.18 (VSS), U1.31 (VSS), U1.47 (VSS), U1.63 (VSS), U2.2 (GND), U2.5 (PS1), U2.15 (GNDIO), U2.16 (GNDIO), U2.25 (GNDIO), U3.3 (GND), U4.12 (GND)
unnamed: D1.2 (A), R4.2
unnamed: D2.2 (A), R7.2
unnamed: D3.2 (A), R9.1
unnamed: D4.2 (A), R10.1
unnamed: R11.2, SW3.2
unnamed: R12.2, SW4.2
unnamed: C3.1, U2.9 (CAP)
unnamed: R3.2, U4.4 (BX_RX)
unnamed: R2.2, U4.2 (BX_TX)
unnamed: SW2.1, U4.16 (PIO0)
unnamed: R4.1, U4.15 (PIO1)
VDC: J2.3, J2.4

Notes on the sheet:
Boot pin
UART5_RX
Decoupling capacitors
UART1_RX
Reset button
32.768KHz RTC for IMU
Bluetooth
Debug buttons
Voltage regulator
8MHz oscillator
2.8V @ 0.18mA
32KHz crystal
UART1_TX
Mounting holes
UART5_TX
Programming header
2.8V @ 0.4mA
Microcontroller
UART-RVC Config PS0 = 1 / PS1 = 0
Debug LEDs
IMU

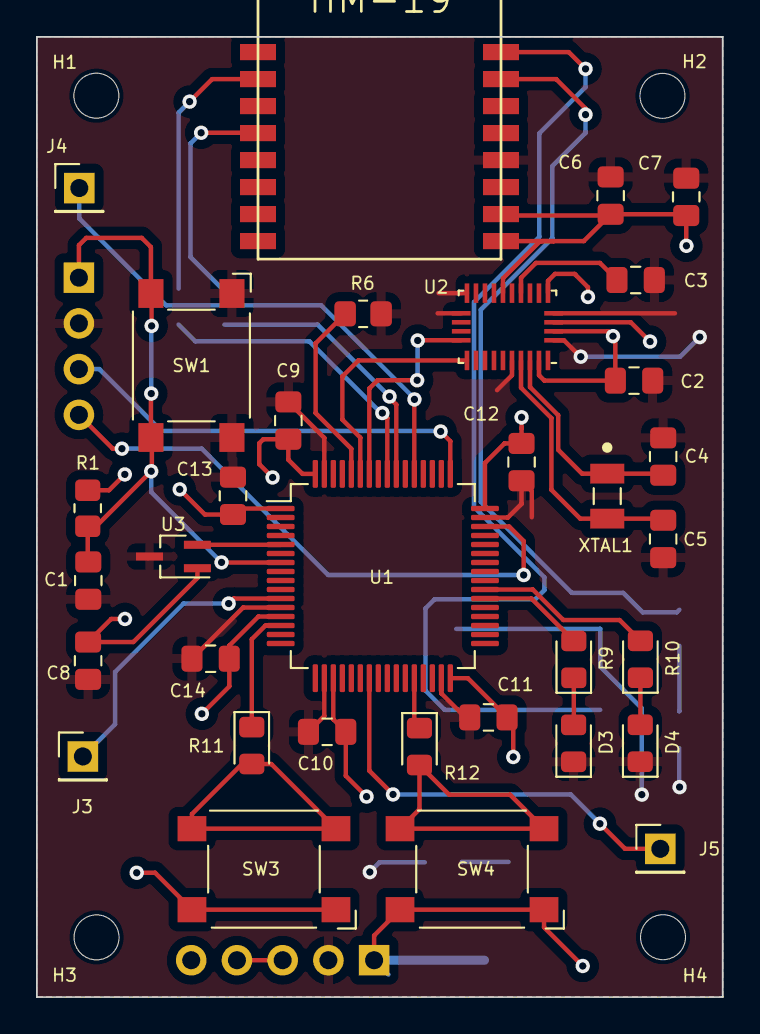
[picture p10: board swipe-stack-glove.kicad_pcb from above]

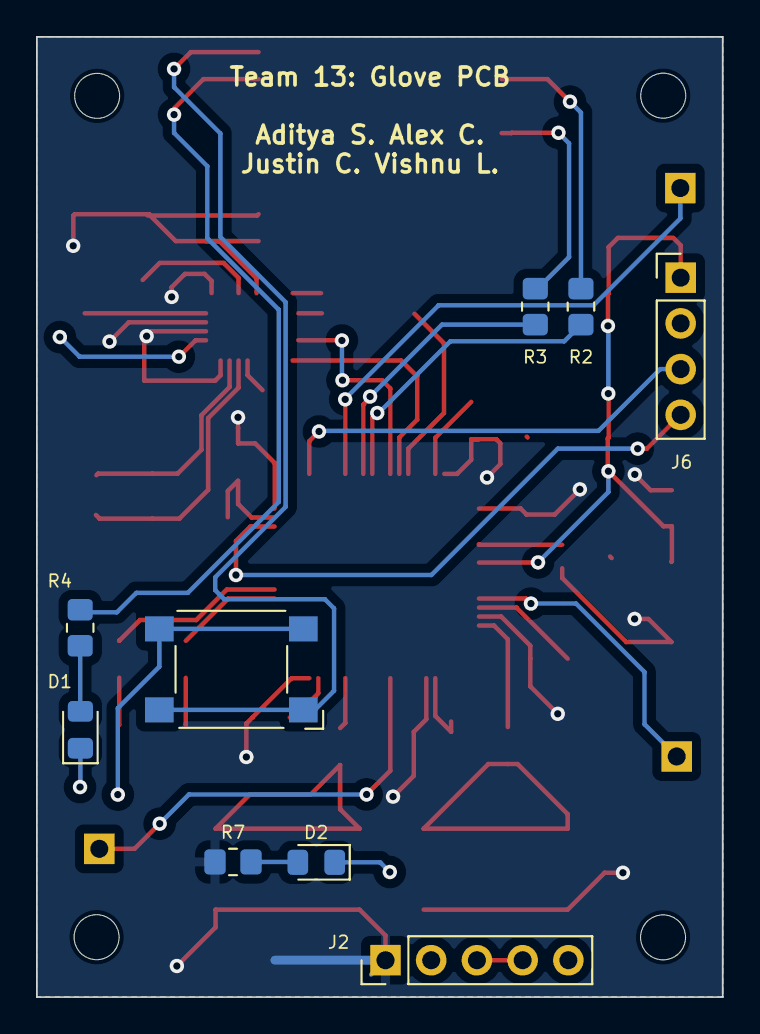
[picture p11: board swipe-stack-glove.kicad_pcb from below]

Board: 2 copper layers, 38.1 x 53.3 mm, 46 parts (9 on the bottom side), 32 nets.

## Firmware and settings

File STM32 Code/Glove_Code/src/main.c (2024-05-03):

/**
  ******************************************************************************
  * @file    main.c
  * @author  Ac6
  * @version V1.0
  * @date    01-December-2013
  * @brief   Default main function.
  ******************************************************************************
*/

/** Pin definitions:

  PB3 -> UART5_TX -> B_RX
 B_TX -> UART5_RX -> PB4

    PB5 -> UART1_TX -> IMU_RX (not used)
 IMU_TX -> UART1_RX -> PB6

**/

#include "stm32f0xx.h"
#include <string.h>

// asm function to waste
// CPU clocks
void
nano_wait(unsigned int n)
{
  asm("        mov r0,%0\n"
      "repeat: sub r0,#83\n"
      "        bgt repeat\n" : : "r"(n) : "r0", "cc");
}

// *****************************************
// BLUETOOTH CODE **************************
// *****************************************

// if configured as slave and IMME1, make yourself discoverable
void sendATStart()
{
	char *startTx = "AT+START";
	char startRx[8] = {};
	for(uint32_t i = 0; i < 8; i++)
	{
		while(!(USART5->ISR & USART_ISR_TXE)){}
		USART5 -> TDR = startTx[i];
	}

	for(uint32_t i = 0; i < 8; i++)
	{
		while(!(USART5->ISR & USART_ISR_RXNE)){}
		startRx[i] = USART5 -> RDR;
	}
}

// if configured as master, start discovery of slave peripherals
void sendATDisc()
{
	char *discTx = "AT+DISC?";
	char discRx[8] = {};
	for(uint32_t i = 0; i < 8; i++)
	{
		while(!(USART5->ISR & USART_ISR_TXE)){}
		USART5 -> TDR = discTx[i];
	}

	for(uint32_t i = 0; i < 100; i++)
	{
		while(!(USART5->ISR & USART_ISR_RXNE)){}
		discRx[i] = USART5 -> RDR;
	}
}

void sendATConn()
{
	char * conTx = "AT+CONE4E11295FAB6";
	char   conRx[8] = {};

	for(uint32_t i = 0; conTx[i] != '\0'; i++)
	{
		while(!(USART5->ISR & USART_ISR_TXE)){}
		USART5 -> TDR = conTx[i];
	}

}

/** Configure device in master or slave mode
 	 AT+ROLE? -> ask current role
 	 AT+ROLE1 -> set to master
 	 AT+ROLE0 -> set to slave
**/
void setATRole()
{
	char roleTx[8] = "AT+ROLE1"; // SET TO 1
	char roleRx[8] = {};

	for(uint32_t i = 0; i < 8; i++)
	{
		while(!(USART5->ISR & USART_ISR_TXE)){}
		USART5 -> TDR = roleTx[i];
	}

	for(uint32_t i = 0; i < 8; i++)
	{
		while(!(USART5->ISR & USART_ISR_RXNE)){}
		roleRx[i] = USART5 -> RDR;
	}
}

/** Configure how the bluetooth module startups
 	 AT+IMME1 -> if slave, wait for AT+START to advertise
			  -> if master, wait for AT+DISC to discover
 	 AT+IMME0 -> start working from get go.
**/
void setATImme()
{

	char immeTx[8] = "AT+IMME1"; // SET TO 1
	char immeRx[8] = {};

	for(uint32_t i = 0; i < 8; i++)
	{
		while(!(USART5->ISR & USART_ISR_TXE)){}
		USART5 -> TDR = immeTx[i];
	}

	for(uint32_t i = 0; i < 8; i++)
	{
		while(!(USART5->ISR & USART_ISR_RXNE)){}
		immeRx[i] = USART5 -> RDR;
	}
}

// change name of bluetooth module (preserved across power outs)
void setBxName()
{
	  // set name of bluetooth device
	  char* nameTx = "AT+NAMEGloveR";
	  char nameRx[14]  = {};

	  // send "AT" test command
	  for(uint32_t i = 0; nameTx[i] != '\0'; i++)
	  {
		  while(!(USART5->ISR & USART_ISR_TXE)){}
		  USART5 -> TDR = nameTx[i];
	  }

	  for(int i = 0; i < 14; i++)
	  {
		  while (!(USART5->ISR & USART_ISR_RXNE)) {}
		  nameRx[i] = USART5->RDR;
	  }
}

// Factory reset module (CAREFUL)
void sendATRenew()
{
	  // set name of bluetooth device
	  char* nameTx = "AT+RENEW";
	  char nameRx[8]  = {};

	  // send "AT" test command
	  for(uint32_t i = 0; i < 8; i++)
	  {
		  while(!(USART5->ISR & USART_ISR_TXE)){}
		  USART5 -> TDR = nameTx[i];
	  }

	  for(int i = 0; i < 8; i++)
	  {
		  while (!(USART5->ISR & USART_ISR_RXNE)) {}
		  nameRx[i] = USART5->RDR;
	  }
}

// Soft reset module (usually after changing config settings)
void sendATReset()
{
	  // set name of bluetooth device
	  char* nameTx = "AT+RESET";
	  char nameRx[8]  = {};

	  // send "AT" test command
	  for(uint32_t i = 0; i < 8; i++)
	  {
		  while(!(USART5->ISR & USART_ISR_TXE)){}
		  USART5 -> TDR = nameTx[i];
	  }
}

// Directly connect to a specified device through MAC Address
void sendATCon()
{
	char * conTx = "AT+CONE4E11295FAB6";
	char   conRx[8] = {};

	for(uint32_t i = 0; conTx[i] != '\0'; i++)
	{
		while(!(USART5->ISR & USART_ISR_TXE)){}
		USART5 -> TDR = conTx[i];
	}

	for(uint32_t i = 0; i < 8; i++)
	{
		while(!(USART5->ISR & USART_ISR_RXNE)){}
		conRx[i] = USART5 -> RDR;
	}
}

void setup_BX_GPIO()
{
	RCC -> AHBENR |= RCC_AHBENR_GPIOBEN;                    // Enable GPIO clock
	GPIOB -> MODER |= GPIO_MODER_MODER3_1; 					// PB3 is TX to Bluetooth (Alt Mode)
	GPIOB -> AFR[0] |= 0x4 << 12;							// PB3 selected for USART5_TX
	GPIOB -> MODER |= GPIO_MODER_MODER4_1; 					// PB4 is RX from Bluetooth (Alt Mode)
	GPIOB -> AFR[0] |= 0x4 << 16; 							// PB4 selected for USART5_RX
}

void setup_BX_UART()
{
	RCC -> APB1ENR |= RCC_APB1ENR_USART5EN;                // clock on for USART5
	USART5 -> CR1 &= ~USART_CR1_UE;                        // turn off for config
	USART5 -> CR1 &= ~USART_CR1_M;                         // 8 bit word length
	USART5 -> CR2 &= ~USART_CR2_STOP;                      // 1 stop bits
	USART5 -> CR1 &= ~USART_CR1_PCE;                       // parity disable
	USART5 -> CR1 &= ~USART_CR1_OVER8;                     // 16x oversampling
	USART5 -> BRR = 48000000 / 9600;					   // 9600 baud rate
	USART5 -> CR1 |= USART_CR1_TE;				           // transmitter enable
	USART5 -> CR1 |= USART_CR1_RE;				           // receiver enable
	USART5 -> CR1 |= USART_CR1_UE;                         // enable usart

	while(!(((USART5 -> ISR) & USART_ISR_TEACK) && ((USART5 -> ISR) & USART_ISR_REACK))); // wait for TEACK and REACK to be set
}

void BluetoothSetup()
{
//	sendATRenew();
//	setBxName();
//	setAdvInterval();
//	setATRole();
//	setATImme();
//	sendATDisc();
//	sendATCon();
//	sendATReset();
//	sendATStart();
//	sendATDisc();
	sendATConn(); // CALL TO PAIR

}

// *****************************************
// IMU CODE ********************************
// *****************************************

// sizing constants
#define FIFOSIZE 					19								// # of bytes to receive from IMU into temp buffer before processing
#define PREDICTIONS_PER_SECOND 	5 								// # of times the entire toolchain runs to display a output
#define PACKET_SIZE				100 / PREDICTIONS_PER_SECOND 	// # of samples that must be filled in before calculating an output

// gesture senstivity thresholds
#define DEADZONE_PITCH				4								// up and down twist dead zone
#define PITCH_UP_LIMIT				25								// rotate
#define PITCH_DN_LIMIT				26								// place down

#define DEADZONE_YAW 				4								// left and right twist dead zone
#define YAW_LFT_LIMIT 				21								// swipe left
#define YAW_RGT_LIMIT				16								// swipe right

uint8_t data_fifo[FIFOSIZE];

uint8_t startup = 'Y';
int init_yaw = 0;
int curr_sample_num = 0;
char last_gesture = 'N';

struct Packet
{
	float pitch [PACKET_SIZE];
	float yaw [PACKET_SIZE];
};

struct Packet curr_packet;


float convertToFloat(uint8_t lsb, uint8_t msb)
{
	int16_t result = ((int16_t) msb << 8) | lsb;
	int8_t decimal_part = result % 100;
	int16_t integer_part = result / 100;
	float final_number = integer_part + (float) decimal_part / 100.0;
	return final_number;
}

void detect_gesture(struct Packet curr_packet)
{
    int down_pitch_count = 0;
    int up_pitch_count = 0;
    int left_yaw_count = 0;
    int right_yaw_count = 0;

    for (int i = 0; i < PACKET_SIZE; i++)
    {
        if (curr_packet.pitch[i] < -(DEADZONE_PITCH + PITCH_UP_LIMIT))
        {
            up_pitch_count++;
        }
        if(curr_packet.pitch[i] > (DEADZONE_PITCH + PITCH_DN_LIMIT))
        {
        	down_pitch_count++;
        }
        if(curr_packet.yaw[i] > (DEADZONE_YAW + YAW_RGT_LIMIT))
		{
			right_yaw_count++;
		}
		if(curr_packet.yaw[i] < -(DEADZONE_YAW + YAW_LFT_LIMIT))
		{
			left_yaw_count++;
		}
    }

    if (down_pitch_count >= PACKET_SIZE / 2)
    {
        sendBxChar('D');
        last_gesture = 'D';
    }
    else if (up_pitch_count >= PACKET_SIZE / 2)
	{
		sendBxChar('U');
		last_gesture = 'U';
	}
    else if (left_yaw_count >= PACKET_SIZE / 2)
	{
		sendBxChar('L');
        last_gesture = 'N';
	}
	else if (right_yaw_count >= PACKET_SIZE / 2)
	{
		sendBxChar('R');
		last_gesture = 'N';
	}
    else
	{
    	last_gesture = 'N';
	}
}

void DMA1_CH2_3_DMA2_CH1_2_IRQHandler()
{
	if(data_fifo[0] == 0xAA && data_fifo[1] == 0XAA)
	{
		if(curr_sample_num == PACKET_SIZE)
		{
			curr_sample_num = 0;
			detect_gesture(curr_packet);
		}
		else
		{
			DMA1 -> IFCR |= DMA_IFCR_CTCIF3;
			curr_packet.yaw[curr_sample_num] = convertToFloat(data_fifo[3], data_fifo[4]) - init_yaw;
			curr_packet.pitch[curr_sample_num] = convertToFloat(data_fifo[5], data_fifo[6]);
			if(startup == 'Y')
			{
				init_yaw = curr_packet.yaw[curr_sample_num];
				startup = 'N';
			}
			curr_sample_num += 1;
		}
	}
	else
	{
		DMA1_Channel3->CCR &= ~DMA_CCR_EN;
		setup_IMU_DMA();
	}
}

void EXTI0_1_IRQHandler()
{
	EXTI->PR |= EXTI_PR_PR0;
	sendBxChar('X');
}

void setup_IMU_GPIO(void)
{
	RCC->AHBENR |= RCC_AHBENR_GPIOBEN;					// portB clock
	GPIOB->MODER &= ~(GPIO_MODER_MODER7);				// clearing PB7 to input
	GPIOB->MODER |= GPIO_MODER_MODER7_1; 				// setting PB7 to AFR mode (UART)
	GPIOB->AFR[0] &= ~(GPIO_AFRL_AFRL7); 	   			// selecting AF0 for PB7

	RCC->APB2ENR |= RCC_APB2ENR_SYSCFGCOMPEN;  			// enable syscfg clock
	SYSCFG->EXTICR[0] &= SYSCFG_EXTICR1_EXTI0_PA; 		// enable pa0 on EXTI0
	RCC->AHBENR |= RCC_AHBENR_GPIOAEN;					// portA clock
	GPIOA->MODER &= ~(GPIO_MODER_MODER0);				// clearing PA0 to
	EXTI->RTSR |= EXTI_RTSR_TR0;						// interrupt on Rising edge PA0
	EXTI->IMR |= EXTI_IMR_MR0;							// enable PA0 interrupt
	NVIC->ISER[0] |= (1 << EXTI0_1_IRQn);
}

void setup_IMU_UART(void)
{
	RCC -> APB2ENR |= RCC_APB2ENR_USART1EN;             // clock on for usart1
	USART1 -> CR1 &= ~USART_CR1_UE;                     // turn off for config
	USART1 -> CR1 &= ~USART_CR1_M;                      // 8 bit word length
	USART1 -> CR2 &= ~USART_CR2_STOP;                   // 1 stop bits
	USART1 -> CR1 &= ~USART_CR1_PCE;                    // parity disable
	USART1 -> CR1 &= ~USART_CR1_OVER8;                  // 16x oversampling
	USART1 -> BRR = 48000000 / 115200;					// 115200 baud rate
	USART1 -> CR1 |= USART_CR1_RE;				        // receiver enable
	USART1 -> CR3 |= USART_CR3_DMAR;					// come dma steal my data
	USART1 -> CR1 |= USART_CR1_UE;                      // enable usart
}

void setup_IMU_DMA()
{
	RCC->AHBENR |= RCC_AHBENR_DMA1EN;
	DMA1_Channel3->CCR &= ~DMA_CCR_EN;      			// turn off enable bit
	DMA1_Channel3->CMAR = (uint32_t) data_fifo;    	 	// cmar address (read to here)
	DMA1_Channel3->CPAR = (uint32_t) &(USART1->RDR); 	// cpar address (read from here)
	DMA1_Channel3->CNDTR = FIFOSIZE;        			// cndtr set to 8
	DMA1_Channel3->CCR &= ~DMA_CCR_DIR;     			// read from perip
	DMA1_Channel3->CCR &= ~DMA_CCR_MSIZE;   			// 16 bit m size
	DMA1_Channel3->CCR &= ~DMA_CCR_PSIZE;   			// 16 bit p size
	DMA1_Channel3->CCR |= DMA_CCR_MINC;     			// increment CMAR
	DMA1_Channel3->CCR |= DMA_CCR_CIRC;					// circular mode
	DMA1_Channel3->CCR |= DMA_CCR_PL_0 | DMA_CCR_PL_1;  // highest priority
	DMA1_Channel3->CCR |= DMA_CCR_TCIE; 				// int on transfer complete
	DMA1_Channel3->CCR |= DMA_CCR_EN;					// enable for dma
	NVIC -> ISER[0] |= (1 << DMA1_Ch2_3_DMA2_Ch1_2_IRQn);
}

void sendBxChar(char txdata)
{
	if (txdata != last_gesture)
	{
	while(!(USART5->ISR & USART_ISR_TXE)) {}
  	USART5->TDR = txdata;
	}
}

//void debugSend(char txdata) {
//  while(!(USART5->ISR & USART_ISR_TXE)){}
//      USART5->TDR = txdata;
//}
//
//void debugSendString(char* data) {
//  int i = 0;
//  while(data[i] != '\0') {
//    debugSend(data[i]);
//    i++;
//  }
//}


// ************************************
// CODE ENTRY *************************
// ************************************

int main(void)
{
	// bluetooth
	setup_BX_GPIO();
	setup_BX_UART();
	BluetoothSetup();
	// imu
	setup_IMU_GPIO();
	setup_IMU_DMA();
	setup_IMU_UART();

	while(1)
	{
		asm("wfi");
	}
}

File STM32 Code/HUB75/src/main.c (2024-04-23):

/*
 * main.c
 *
 * Vishnu Lagudu
 * vlagudu@purdue.edu
 *
 * Drive the LED matrix
*/

#include "tetris.h"

pixel_t screen [MEMSIZE];


int
main ()
{
  // set the random seed
  set_random_seed ();
  ss_bluetooth    ();
  setup_oled      ();


//	  splash_screen (screen);
  init_hub(screen);
  while(1)
  {
	  splash_screen (screen);
	  int score = tetris (screen);
	  lose_screen (screen);

  }

  return EXIT_SUCCESS;
}

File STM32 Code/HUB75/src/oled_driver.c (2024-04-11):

/**
 * @brief Includes coinfiguration of peripherals and drivers
 *        that are written for the OLED display.
 * @author Alex Chitsazzadeh (achitsaz@purdue.edu)
**/
#include "oled_driver.h"
#include <stdio.h>

uint16_t score[34] = {
				0x002, // Command to set the cursor at the first position line 1
		        0x200+'S', 0x200+'C', 0x200+'O', 0x200+'R', 0x200+'E', + 0x200+':', 0x200+' ', 0x200+'0',
		        0x200+'0', 0x200+'0', 0x200+'0', 0x200+'0', + 0x200+'0', 0x200+'0', 0x200+'0', 0x200+'0',
		        0x0c0, // Command to set the cursor at the first position line 2
		        0x200+'L', 0x200+'E', 0x200+'V', 0x200+'E', 0x200+'L', + 0x200+':', 0x200+' ', 0x200+' ',
		        0x200+' ', 0x200+' ', 0x200+' ', 0x200+' ', + 0x200+' ', 0x200+' ', 0x200+'0', 0x200+'0',
};


void updt_score(char * scoreBuff, char * levelBuff)
{
    int digitLen = strlen(scoreBuff);
    int levelLen = strlen(levelBuff);
	int scoreIndex = 16;
	int levelIndex = 33;
	while(digitLen != 0)
	{
		score[scoreIndex] = 0x200 + scoreBuff[(digitLen - 1)];
		digitLen--;
		scoreIndex--;
	}
	while(levelLen != 0)
	{
		score[levelIndex] = 0x200 + levelBuff[(levelLen - 1)];
		levelLen--;
		levelIndex--;
	}
}

void init_score()
{
	uint16_t og_score[34] = {
					0x002, // Command to set the cursor at the first position line 1
			        0x200+'S', 0x200+'C', 0x200+'O', 0x200+'R', 0x200+'E', + 0x200+':', 0x200+' ', 0x200+'0',
			        0x200+'0', 0x200+'0', 0x200+'0', 0x200+'0', + 0x200+'0', 0x200+'0', 0x200+'0', 0x200+'0',
			        0x0c0, // Command to set the cursor at the first position line 2
			        0x200+'L', 0x200+'E', 0x200+'V', 0x200+'E', 0x200+'L', + 0x200+':', 0x200+' ', 0x200+' ',
			        0x200+' ', 0x200+' ', 0x200+' ', 0x200+' ', + 0x200+' ', 0x200+' ', 0x200+'0', 0x200+'0',
	};

	memcpy(score, og_score, sizeof(og_score));
}

void setup_oled()
{
	setupGPIO_spi();
    init_spi1();
    spi1_init_display();
    spi1_setup_dma();
}




void setupGPIO_spi(){
	// PA5  SPI1_SCK
	// PA6  SPI1_MISO
	// PA7  SPI1_MOSI
	// PA15 SPI1_NSS

	// GPIOA config
	RCC -> AHBENR |= RCC_AHBENR_GPIOAEN;
	GPIOA -> MODER &= ~(GPIO_MODER_MODER5  | GPIO_MODER_MODER6 | GPIO_MODER_MODER7 | GPIO_MODER_MODER15);
	GPIOA -> MODER |= (GPIO_MODER_MODER5_1 | GPIO_MODER_MODER6_1 | GPIO_MODER_MODER7_1 | GPIO_MODER_MODER15_1);
	// ports correspond to AF0 according to table
	GPIOA -> AFR[0] &= ~(0xf << (4 * 5));        // clr AFR5 -> using AF0
	GPIOA -> AFR[0] &= ~(0xf << (4 * 6));        // clr AFR6 -> using AF0
	GPIOA -> AFR[0] &= ~(0xf << (4 * 7));        // clr AFR7 -> using AF0
	GPIOA -> AFR[1] &= ~(0xf << (4 * (15 - 8))); // clr AFR15 -> using AF0
}

void init_spi1(){
	// PA5  SPI1_SCK
	// PA6  SPI1_MISO
	// PA7  SPI1_MOSI
	// PA15 SPI1_NSS

	// SPI1 config
	RCC -> APB2ENR |= RCC_APB2ENR_SPI1EN;
	SPI1 -> CR1 &= ~SPI_CR1_SPE; // disable SPI channel
	SPI1 -> CR1 |= SPI_CR1_BR; // BR = 111 -> fclk / 256
	SPI1 -> CR2 = SPI_CR2_DS_0 | SPI_CR2_DS_3; // 10 bit word size
	SPI1 -> CR1 |= SPI_CR1_MSTR; // set spi channel to MASTER mode
	SPI1 -> CR2 |= SPI_CR2_SSOE; // set slave select output enable bit
	SPI1 -> CR2 |= SPI_CR2_NSSP; // automatically pulse NSS between data transfers
	SPI1 -> CR2 |= SPI_CR2_TXDMAEN; // when transmit buffer empty, trigger DMA
	SPI1 -> CR1 |= SPI_CR1_SPE; // enable SPI channel
}

void spi1_setup_dma(void)
{
    // Note: SPI1_TX works with DMA Channel 3
    // enable clock for DMA
    RCC -> AHBENR |= RCC_AHBENR_DMAEN;
    DMA1_Channel3 -> CCR &= ~DMA_CCR_EN; // turn off DMAch3
    // set CPAR to SPI1 -> DR address
    DMA1_Channel3 -> CPAR = (uint32_t) &(SPI1 -> DR);
    // set CMA to display array base address
    DMA1_Channel3 -> CMAR = (uint32_t) score;
    // set to transfer 34 'elements' total
    DMA1_Channel3 -> CNDTR = 34;
    // set DIR for mem -> peripheral
    DMA1_Channel3 -> CCR |= DMA_CCR_DIR; // read from mem
    // set MINC to increment CMAR upon each transfer
    DMA1_Channel3 -> CCR |= DMA_CCR_MINC;
    // set memory data size to 16-bit and peripheral size to 16 bit
    DMA1_Channel3 -> CCR &= ~DMA_CCR_MSIZE; // clr msize
    DMA1_Channel3 -> CCR &= ~DMA_CCR_PSIZE; // clr psize
    DMA1_Channel3 -> CCR |= 0x00000500; // set p and m to 16 bits
    // set to circular operation
    DMA1_Channel3 -> CCR |= DMA_CCR_CIRC;

    DMA1_Channel3 -> CCR |= DMA_CCR_EN; // turn on DMAch3
}

void spi_cmd(unsigned int data)
{
    while(!(SPI1->SR & SPI_SR_TXE)) {}
    SPI1->DR = data;
}

void spi1_init_display()
{
    nano_wait(1000000); // wait 1 ms
    spi_cmd(0x38); // set for 8-bit operation
    spi_cmd(0x08); // turn display off
    spi_cmd(0x01); // clear display
    nano_wait(2000000); // wait 2 ms
    spi_cmd(0x06); // set display to scroll
    spi_cmd(0x02); // move cursor to home position
    spi_cmd(0x0c); // turn display on
}

void spi1_display1(const char *string)
{
    spi_cmd(0x02); // move cursor to home position
    while(*string != '\0')
    {
        spi_cmd(*string | 0x200); // write char to DDRAM
        string++;
    }
}

void spi1_display2(const char *string)
{
	spi_cmd(0xc0); // move cursor to lower row (offset 0x40)
    while(*string != '\0')
    {
        spi_cmd(*string | 0x200); // write char to DDRAM
        string++;
    }
}

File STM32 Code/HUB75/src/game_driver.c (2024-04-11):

/**
 * @brief Includes coinfiguration of peripherals and drivers
 *        that are mainly written for the game logic
 * @author Vishnu Lagudu (vlagudu@purdue.edu)
 *         Alex Chitsazzadeh (achitsaz@purdue.edu)
**/

# include "game_driver.h"

/* Peripheral Coinfiguration */

/**
  * @brief Coinfigure the ADC inorder to use its DR (Data Registers)
  *        as a seed for the srand () function given by stdlib.
  * @param None
  * @retval None
**/
void 
setup_adc (void)
{
  RCC->AHBENR |= RCC_AHBENR_GPIOCEN;
  GPIOC->MODER |= 0x3 << 6;

  RCC->APB2ENR |= RCC_APB2ENR_ADC1EN;
  RCC -> CR2 |= RCC_CR2_HSI14ON;
  // Wait for 14MHz internal clk
  while (!(RCC -> CR2 & RCC_CR2_HSI14RDY));

  // enable the ADC
  ADC1 -> CR |= ADC_CR_ADEN;
  // Wait for ADC ready
  while (!(ADC1 -> ISR & ADC_ISR_ADRDY));
  ADC1 -> CHSELR = ADC_CHSELR_CHSEL13;
  while (!(ADC1 -> ISR & ADC_ISR_ADRDY));
  
  // start the ADC
  ADC1 -> CR |= ADC_CR_ADSTART;
  // Wait for end of conversion
  while(!(ADC1->ISR & ADC_ISR_EOC));
}

/**
  * @brief Upcounting Timer 3 which is used to keep track of the
  *        elapsed game time.
  * @param psc: prescaler value that is used to prescale down from
  *        48 MHz to desired frequency.
  * @param arr: maximumn value that the timer can count up to at which
  *        time Interrupt gets triggered.
  * @retval None
**/
void
setup_tim3 (uint32_t psc, uint32_t arr)
{
  // Turn on the clock for timer 3
  RCC -> APB1ENR |= RCC_APB1ENR_TIM3EN;

  // set the clk freq
  TIM3->PSC = psc-1;
  TIM3->ARR = arr-1;

  // Set for Upcounting
  TIM3->CR1 &= ~TIM_CR1_DIR;
  TIM3 -> DIER |= TIM_DIER_UIE;

  // Turn on timer
  TIM3->CR1 |= TIM_CR1_CEN;
  // enable tim3 interrupt in NVIC
  NVIC -> ISER[0] |= 0x00010000; 
}

/**
  * @brief This function is used to coinfigure PA8, PC2, and PC1
  *        as external interrupts. These are currently used as 
  *        button interrupts.
  * @param None
  * @retval None
**/
void
init_exti()
{
  RCC -> AHBENR |= RCC_AHBENR_GPIOAEN | RCC_AHBENR_GPIOCEN;
  GPIOA -> MODER &= ~GPIO_MODER_MODER8;
  GPIOC -> MODER &= ~GPIO_MODER_MODER2;
  GPIOC -> MODER &= ~GPIO_MODER_MODER1;
  GPIOA -> PUPDR &= ~GPIO_PUPDR_PUPDR8;
  GPIOC -> PUPDR &= ~GPIO_PUPDR_PUPDR2;
  GPIOC -> PUPDR &= ~GPIO_PUPDR_PUPDR1;
  GPIOA -> PUPDR |= GPIO_PUPDR_PUPDR8_1;
  GPIOC -> PUPDR |= GPIO_PUPDR_PUPDR2_1;
  GPIOC -> PUPDR |= GPIO_PUPDR_PUPDR1_1;

  // 1-2
  RCC -> APB2ENR |= 0x1; // enable bit 0 (SYSCFGCOMPEN)
  SYSCFG -> EXTICR[0] &= 0xfffff00f; // clear port 2 and 1
  SYSCFG -> EXTICR[0] |= 0x00000200; // enable PC2 for EXTI2
  SYSCFG -> EXTICR[0] |= 0x00000020; // enable PC1 for EXTI2
  SYSCFG -> EXTICR[3] &= 0xfffffff0; // clear port 8
  SYSCFG -> EXTICR[3] |= 0x00000000; // enable PA8 for EXTI8

  // 3
  // enable rising edge interrupt on PC2, PA8, PC1
  EXTI -> RTSR |= EXTI_RTSR_TR2;
  EXTI -> RTSR |= EXTI_RTSR_TR8;
  EXTI -> RTSR |= EXTI_RTSR_TR1;

  // 4
  // unmask PC2, PA8 so interrupt can be seen by NVIC
  EXTI -> IMR |= EXTI_IMR_MR2;
  EXTI -> IMR |= EXTI_IMR_MR8;
  EXTI -> IMR |= EXTI_IMR_MR1;

  // 5
  // enable interrupts for EXTI pins 0-1, 2-3, and 4-15 e = 1110
  NVIC -> ISER[0] |= 0xe0;
}

/* IRQ Handlers for Interrupts */

void
TIM3_IRQHandler()
{
  TIM3 -> SR &= ~(TIM_SR_UIF);
  fall_time += 1;

}

void EXTI0_1_IRQHandler()
{
  // clear pending flag for pc1
  EXTI -> PR = 0x2;
  KEY_ROT = true ;
}

void EXTI2_3_IRQHandler()
{
  // clear pending flag for pc2
  EXTI -> PR = 0x4; // clear pending flag for pc2
  KEY_LEFT = true;

}

void EXTI4_15_IRQHandler()
{
  // clear pending flag for pa8
  EXTI -> PR = 0x100; // clear pending flag for pa8
  KEY_RIGHT = true;
}

/* Drivers written based on the peripherals */

static void 
board_init (pixel_t * screen)
{
  sr_font (screen, 4, 0, get_board (), WHITE, 1);
}

void
init_hub(pixel_t * screen)
{
// set up the peripherals
  init_io ();
  setup_dma (screen);
  setup_tim2 (10, 2, 1);

  // enable dma transfers
  ed_dma (1);

  // clear screen
  init_screen (screen, BLACK);
  // enable interrupts
  init_exti();
}

void
game_init (pixel_t * screen)
{
  // clear screen
  init_screen (screen, BLACK);
  // draw game border
  board_init (screen);
}

void 
set_random_seed ()
{
  // turn on the ADC
  setup_adc ();

  // rand_seed = (ADC->DR & 0xf) ** 5 
  srand (pow (ADC1->DR & 0xf, 5));
}

void 
clear_row (pixel_t * screen, int y)
{
  uint8_t offset;
  y += 1;
  for(int x = 6; x < 26; x++)
  {
    // Compute the location
    uint16_t loc = (x & 0xf) * HUB75_C + (y * 2);

    if (x > 0xf)
    {
      offset = 3;
    }
    else
    {
      offset = 0;
    }

    // logic to clear the rows
    screen[loc].color &= ~(WHITE << offset);
    screen[loc + 1].color &= ~(WHITE << offset);
  }
}

void 
drop_rows (pixel_t * screen, int row)
{
  row++;
  pixel_t prev;
  uint8_t offset;  

  for(int x = 6; x < 26; x++)
  {
    for(int y = (row * 2); y < 41; y++)
    {
      // calculate the position
      uint16_t loc = (x & 0xf) * HUB75_C + y;

      if(x > 0xf)
      {
        offset = 3;
      }
      else 
      {
        offset = 0; 
      }

      // Logic to drop the rows
      prev = screen[loc];
      // undo previous state
      screen[loc].color &= ~(WHITE << offset);
      // drop the rows
      screen[loc - 2].color |= ((prev.color >> offset) & 0x7) << offset;
    }
  }
}

void
sr_coord_board (pixel_t * screen, coord_t * positions, hub75_color_t color, bool set)
{
  uint8_t offset;
  for (int i = 0; i < SHAPE_NUM_PIX; i++)
  {
    // Bounds check
    if (positions[i].y > BOARD_TOP) continue;

    uint16_t loc = (positions[i].x & 0xf) * HUB75_C + positions[i].y;
    
    if (positions[i].x > 0xf)
    {
      offset = 3;
    }
    else
    {
      offset = 0;
    }
    screen[loc].color &= ~(WHITE << offset);
    if (set)
    {
      screen[loc].color |= color << offset;
    }
  }
}

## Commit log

2024-01-19 bx working
    [TestConfig.cfg]
2024-01-24 RDR register on uart finally working + updated exit success conditions on returns from functions
2024-01-26 Prototype Code for STM32F0 Finished for Now
2024-01-31 Init IMU Code (aditya)
    [IMU.cfg]
2024-02-01 Add HUB75
    [New_configuration.cfg]
2024-02-01 Sending data over DMA / SPI
2024-02-01 Clean communication with IMU
2024-02-02 Create font and driver
2024-02-04 New UART_RVC based IMU working
2024-02-04 New uart-rvc working
    [IMU_UART Run.cfg]
2024-02-05 Updated swipe-stack hub schematic with HM19 modules as well as reset button circuitry for MCU
    [swipe-stack-hub.kicad_sch]
2024-02-06 UART code for iMU
    [swipe-stack-glove.kicad_pcb, swipe-stack-glove.kicad_sch]
2024-02-15 matrix with DMA
    [Matrix Run.cfg]
2024-02-17 playing with the timers
2024-02-19 First cut of hub PCB
    [swipe-stack-hub.kicad_pcb, swipe-stack-hub.kicad_sch]
2024-02-20 Justin's version of hub PCB
    [swipe-stack-hub.kicad_pcb, swipe-stack-hub.kicad_sch]
2024-02-21 Glove PCB rev1
    [IMU.cfg, New_configuration.cfg, TestConfig.cfg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]
2024-02-21 changed some capacitors
    [swipe-stack-hub.csv, swipe-stack-hub.kicad_pcb, swipe-stack-hub.kicad_sch]
2024-02-22 PWM working with packed structs and wavetable go brrrrr
2024-02-28 pcb changes
    [swipe-stack-hub.kicad_pcb, swipe-stack-hub.kicad_sch]
2024-02-29 Latest glove pcb
    [swipe-stack-glove.csv, swipe-stack-glove.kicad_pcb, swipe-stack-glove.kicad_sch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]
2024-02-29 Merged all latest PCBs
2024-03-01 pcb ready for presentation
    [swipe-stack-hub.kicad_pcb]
2024-03-01 My changes
    [swipe-stack-hub.kicad_pcb]
2024-03-03 Roll detection works, cleanup previous IMU code
    [477_debug.cfg, test_debug.cfg]
2024-03-08 gerber done
    [New_configuration (1).cfg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]
2024-03-21 Latest STM32 code. Still need to fix some things by putting them in git ignore
    [Bx Debug.cfg, HUB75 Run.cfg, Oled Run.cfg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]
2024-03-21 Added the correct hub75
    [hub75_driver.c, main.c]
2024-03-22 Fixed the matrix pinout
    [hub75_driver.c, main.c]
2024-03-25 added fall timer and button interrupts
2024-03-29 Fix Heisenbug, add lose condition, queue
    [game_driver.c, main.c]
2024-04-01 Working on glove soft
    [glove_software.cfg]
2024-04-03 IMU code without debouncing motion
2024-04-05 add bluetooth driver
2024-04-05 deprecated old IMU code
    [IMU_UART Run.cfg, New_configuration (1).cfg, New_configuration.cfg]
2024-04-06 Fixed ?
    [glove_code Run.cfg]
2024-04-06 bt driver
2024-04-08 Integrated OLED drivers, scoring system, and leveling system to game logic
2024-04-09 fixed level up logic
    [main.c]
